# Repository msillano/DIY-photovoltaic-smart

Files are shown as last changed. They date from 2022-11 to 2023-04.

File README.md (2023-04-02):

# DIY-photovoltaic-smart

This study offers an overview of the state of the art and possible alternatives, useful not only for trying their hand at DIY but also for those who have to make choices and evaluate offers in the photovoltaic sector.

Smart photovoltaic projects, with complete technical information, instructions and results:

   - project A: module 300 Wp plug-and-play
   - project B: module 800 / 1000 / 1200 Wp on grid
   - project C: module 800Wp, with limit
   - project D: adding storage to C (1200 Wh)
   - project E: UPS/off-grid hybrid inverter 6200W + storage.
   
Why 'smart'?  All projects they are IOT compatible, therefore they can be controlled remotely and integrated into home automation projects immediately (using the [smartLife](https://play.google.com/store/apps/details?id=com.tuya.smartlife) APP) or via a universal IOT development environment (like [tuyaDAEMON](https://github.com/msillano/tuyaDAEMON)).

---------------

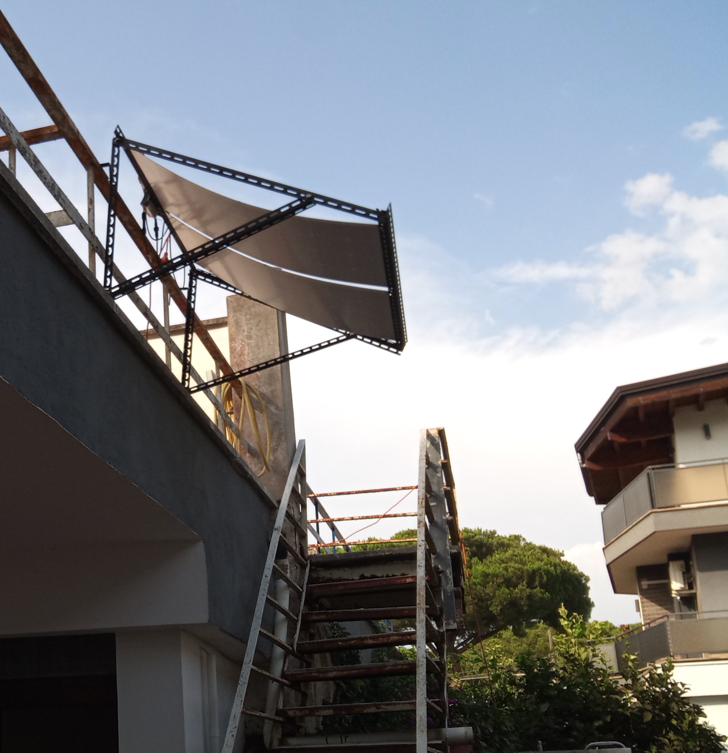
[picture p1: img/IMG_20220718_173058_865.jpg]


Part A: **Preamble about solar, DIY plug-and-play 200/300 Watt**
  - Part A: Wp < 350 W, pdf [english version](fotovoltaico-part-A-v2-en.pdf)
  - Part A: Wp < 350 W, pdf [versione Italiana](fotovoltaico-part-A-v2-it.pdf)
---------------
  
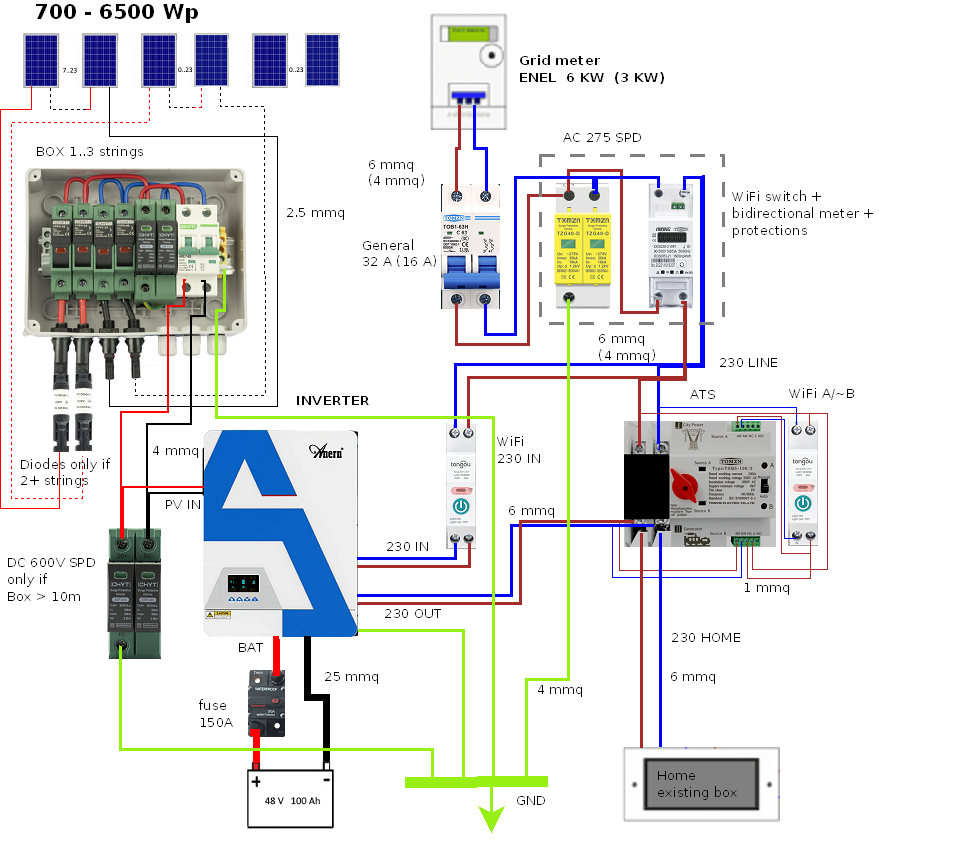
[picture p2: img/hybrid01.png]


Part B: **Usage strategies and DIY photovoltaic > 350 Watt**
  - Part B: Wp > 350 W, pdf [english version](fotovoltaico-part-B-v4-en.pdf) 
  - Part B: Wp > 350 W, pdf [versione Italiana](fotovoltaico-part-B-v4-it.pdf) 

note: _There is a problem with viewing a pdf document within GitHub: the links don't work.
I recommend downloading the pdf file and using a better viewer._

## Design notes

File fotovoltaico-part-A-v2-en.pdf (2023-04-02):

# Photovoltaic today DIY

Part A, ver. 2, 20/02/2023

At the moment, both for the generically green pressures, both for the increases in the electricity bill, both for the problems with fossil fuels, and the government subsidies, photovoltaic systems are on the agenda, in Italy and throughout the world.

As a result, they stick with offers and commercial proposals, which are often smoky and difficult to evaluate.

I try to clarify, sharing both the various analyzes, the projects carried out, and the results obtained, I hope they are useful as a starting point for those who want to try their hand at DIY, and for those who want to evaluate commercial offers.
1. This document is initially a fact-checking, for a correct setting of the problems.
2. Followed by DIY projects of photovoltaic installations less than 350 Wp (plug and play).
3. The next document (Part B) “photovoltaic > 350 Wp” (https://github.com/msillano/DIY-photovoltaic-smart/blob/main/fotovoltaico-part-B-v3-en.pdf) contains more projects.
4. This is a work in progress, with continuous updates. The last version of this document is in the repository https://github.com/msillano/DIY-photovoltaic-smart

The Author is not sponsored or affiliated in any way to any company: the choices are made only on the basis of personal conviction. For the materials, I have tried to favor international suppliers for two reasons:
- Global availability, to be able to carry out these projects anywhere in the world.
- Provide good value for money for comparisons.

Sometimes I refer to the Italian products or the Italian regulatory situation, which I know best, but it is always well highlighted.

Disclaimer
This article is for informational purposes, and is true and accurate to the best of the Author's knowledge, but may contain inadvertent errors or inaccuracies: it is provided "as is", without warranties of any kind, implicit or explicit.

The practical execution of the projects and the sizing calculations of the components and of the electrical connection cables must in any case always be carried out, verified and validated by specialized, competent and qualified technical personnel, in full compliance with all current electrical and safety regulations, which vary according to the country, therefore the Author is not responsible for direct or indirect accidental damages caused by the use of the information provided.

Preamble: simulations

An online simulator can be used to evaluate the potential of photovoltaics.

There are many, the most used (in Europe) is the European Union's PVGIS Photovoltaic Geographical Information System. (https://re.jrc.ec.europa.eu/pvg_tools/en/) I use it often, both in the design phase and in the test phase.

Another good simulator is PVWATTS (https://pvwatts.nrel.gov/pvwatts.php) (NREL-National Renewable Energy Laboratory, USA), analogous to PVGIS.

With PVWATTS you get lower kWh per year than PVGIS (they use different weather data), on the plus side it has an editable satellite map and the ability to analyze the losses in detail.

For an immediate first test, using the optimized values with PVGIS:
1. Choose the location on the map, or enter an address, or the Lat / Lon values
2. For now, select Calculated horizon

Using the 'GRID CONNECTED' tab:
1. Let's set a reference value of 1 (1 kWp) as ‘Installed peak PV power [kWp]’.
2. We select ‘Mounting position’ = ‘Free-standing’ (i.e. with circulating air in the back).
3. We also check the ‘Optimize slope and azimuth’.

Then the button: Visualize results, and then PDF.

The following result is obtained (the location is Rome. Italy):

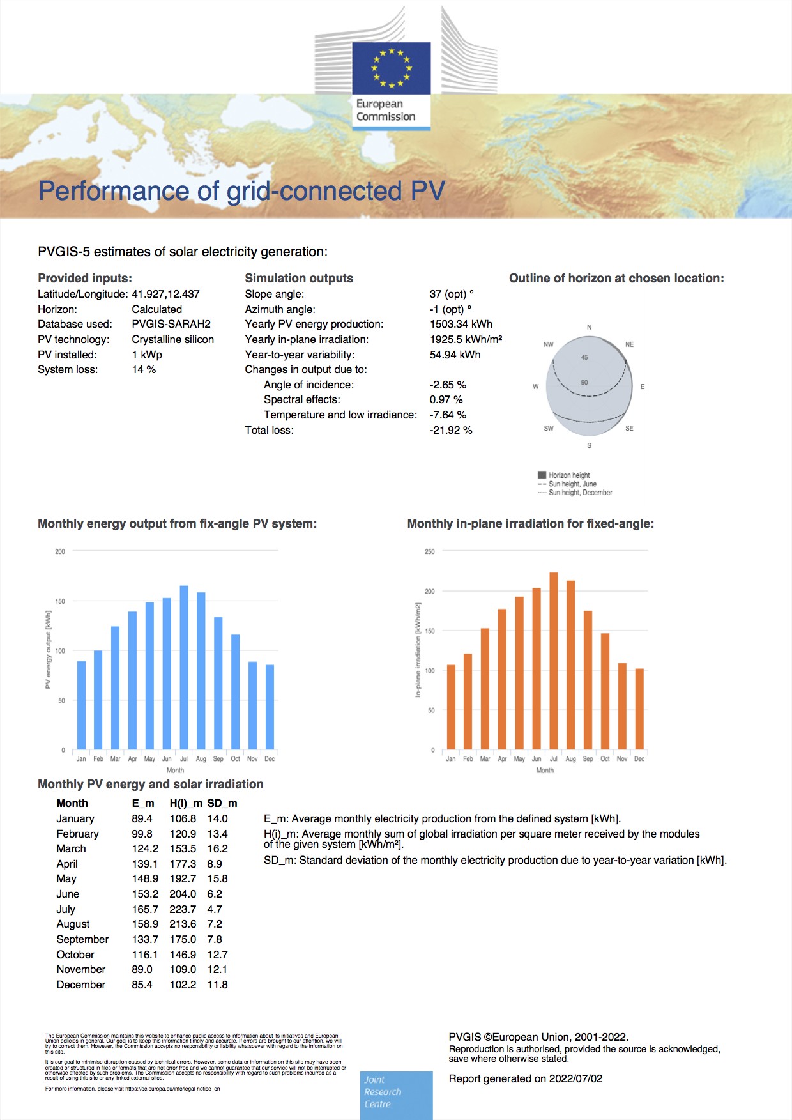
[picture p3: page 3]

Let's analyze some results we get from the simulation:

1. The optimal inclination (slope) of the panel from the horizontal is 37°
2. The theoretical orientation (azimuth) is SOUTH (0°) or noon, but the optimal in this case is 1 ° towards WEST.
3. The calculated horizon, which takes into account natural obstacles, such as mountains and hills, is practically clear: only a small hill at E delays the sunrise (hence the 1 ° correction of the Azimuth).
4. Going with the mouse on the Sun Heigth curves, we find the height of the sun at noon: in June (71°) and in December (24°). From these values derives the optimal proposed value of 37°.
5. In one year the (average, optimal) production of electricity is estimated to be 1503.34 kWh per 1 KWp installed.
6. The month of maximum production is July (165.7 kWh) while the minimum is in December (85.4 kWh).
7. The standard deviation (SD_m) is also indicated for each month, which is a measure of variability. It can be simplified as follows: based on the data of previous years there is a 95% probability of observing an energy production between (E_m – 2*SD_m) and (E_m + 2*SD_m) for the month considered (see 68- 95-99.7 rule). (https://en.wikipedia.org/wiki/68%E2%80%9395%E2%80%9399.7_rule)

The DAILY DATA option, chose a month, provides the average daily irradiation profile.

Clear-sky: does not take into account atmospheric absorption (dust and clouds).

Note: Does not take into
account daylight saving time (DST).

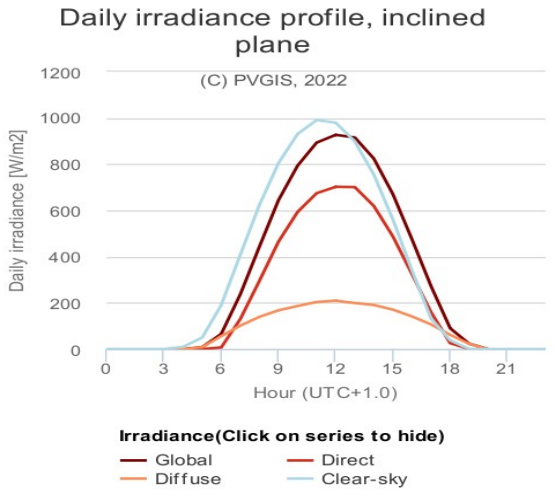
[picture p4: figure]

These are the starting data for the chosen location (in the example, Rome) in optimal conditions.

In practice, what are the factors to be taken into account in the project?
The same as required by the simulation:
- Latitude and longitude of the installation.
- Surface (i. E. KWp) of solar panels, type.

- Mounting system with circulating air (preferable, 'Free-standing') or on a surface ('roof adding') as required in some cases: the efficiency of the panel decreases with the increase in temperature.
- Shadows and geographical and local obstacles, e.g. buildings and trees: are considered by building a custom 'horizon file' (click on 'Upload horizon file' for info) for a given location.
- Slope, or horizontal angle (if fixed)
- Azimuth or orientation (if fixed)
- As an alternative to fixed angles, you can also consider the 'TRACKING PV' option, which is a mechanical tracking system, which transforms the solar panel into a sunflower.

Another fixed point: with standard monocrystalline panels (the most efficient, efficiency >= 20%) the equation applies:

1 square meter = 200 Wp

Use this formula as a litmus test to evaluate offers for solar systems and panels: if an offer promises 1 kWp (1000 Wp), the panels MUST be at least 5 m²
!

Notes: a simulator is simply a sophisticated calculation system based on some assumptions. The results obtained must be verified.

balcony solar panel.

This type of photovoltaic system (called also plug-and-play) is designed for urban users, who live in apartments in the city. The system is very simple and must be thought of as any household appliance: the panels can be installed by the end user in many ways, and they can also be moved. The presence of a plug is essential: these devices do not have to be hard-wired.
These installations aim to reduce the cost of the electricity bill.

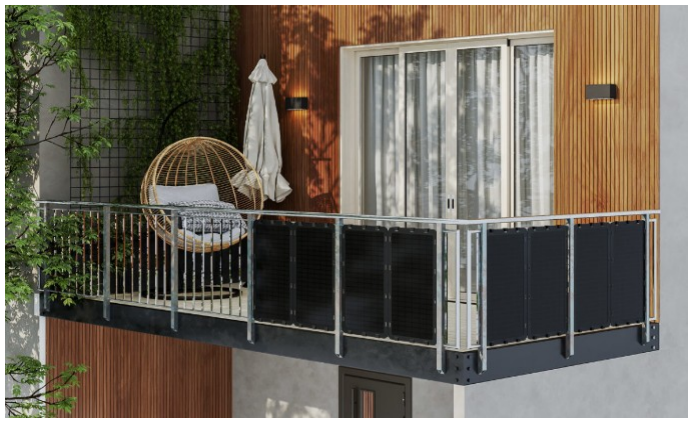
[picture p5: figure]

Example 1: Flexible panels are attached directly vertically to an existing railing.

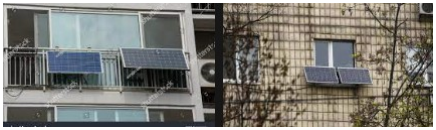
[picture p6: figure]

Example 2: Balcony and window: use of supports to improve the angle of inclination.

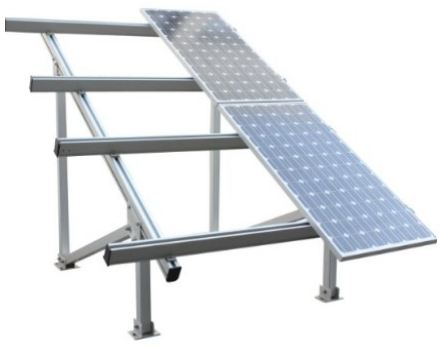
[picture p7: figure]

Example 3: self-supporting for terraces.

Italian commercial example: Enel-x-sun plug-play (https://www.enelxstore.com/it/it/prodotti/campagne/speciale-enel-x-sun-plug-play)

Kit:
1 * rigid solar panel 196 cm * 100 cm, 340 Wp, 1.9 m²
, weight 19 Kg (datasheet) (https://www.enelxstore.com/content/dam/enel-x-store-it/prodotti_catalogo/fotovoltaico/plug-e-play/Specifiche-tecniche-modulo-fotovoltaico-plug-n-play.pdf) 1 * holder, 3 options, weight 7 Kg
(see the manual (https://www.enelxstore.com/content/dam/enel-x-store-it/prodotti_catalogo/fotovoltaico/plug-e-play/Manuale_installazione-plug-n-play-10-06-2020.pdf) in Italian).
1 * inverter, 380 W MPPT TSUN TSOL M350 (https://www.ipersolar.com/it/inverter-grid-connect/1657-microinverter-TSOL300-per-impianti-fino-a-380w.html) 1 * switch + power meter.
Independent video. (https://www.youtube.com/watch?v=mVmnkkBSPkA)
Price: | 649 €
Cost per kWp: | 1900 €

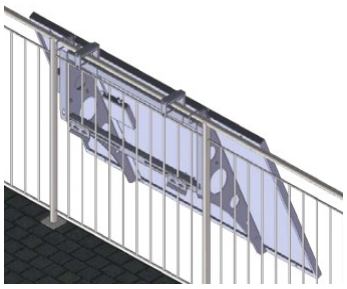
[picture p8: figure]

Italian commercial example: LaCasaDelSole (https://www.lacasadelsolestore.com/index.php?id_product=263&controller=product) Kit:
1 * panel 169 x 99 cm. = 1.6 m², 340 W
1 * inverter TSOL-M350 (certified CEI 0-21) (https://www.lacasadelsolestore.com/index.php?controller=attachment&id_attachment=69)
Price | 650 €
Cost per kWp: | 1’900 €

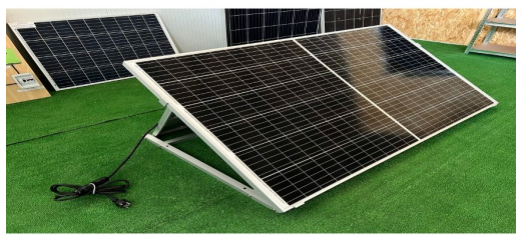
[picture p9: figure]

Commercial example: German startup We Do Solar (https://www.pv-magazine.com/2022/05/17/1-kg-balcony-solar-module-you-can-install-yourself/)

Kit :
8 * flexible solar panels 90 cm * 54 cm (80 Wp), total: 3.8 m²
| , 640 Wp (datasheet) (https://uploads-ssl.webflow.com/61a53640ae89f22ed614b1a3/6263ec536d99d9a6252288c0_Datenblatt.pdf)
1 * Inverter 600 W MPPT
Price: | 1’299 €
Cost per kWp: | 2’170 €

Italian business example: eet-solare. (https://www.eet-solare.it/it/setup/) Kit::
1* Photovoltaic Panel 166 x 100, 370 Wp (MaySun) 1* Inverter Envertec EVT300 MPPT
Mounting accessories
Price | 539 €
Cost per kWp | 1’457 €

Analyses

A series of factors intervene to reduce performance, especially in this type of installation:

### 1. Shadows

Even a small shadow (a leaf) can drastically reduce the performance of a solar panel: this depends on how topologically the individual cells of the panel are connected. If, for example, they are connected in 3 groups, a single cell in the shade leads to a 33% drop in the production of the panel.
The panels connected in series are all affected by the same decline. However, it is possible to use 'power optimizers' which substantially decouple the panels from each other. Similarly, if more panels are connected in parallel, they can be decoupled with protection diodes.

Note: For an evaluation of the shadows of the nearest obstacles (buildings, chimneys, trees, etc.) at various hours and various months, it is possible to use, in addition to the custom definition of the horizon in PVGIS, also a 3D model made with SketchUp-free, (https://www.sketchup.com/it/plans-and-pricing/sketchup-free) as recommended by milliWatt. (https://www.energialternativa.info/public/newforum/Discussione.php?213369)

3. Azimuth
The optimal orientation is the SOUTH, but it is not certain that it is available. Fortunately, the losses are limited: to get an idea of the problem, here is a simple table obtained with PVGIS.
Percentages of annual production (slope = 37°):
SUD 0° | 100%
10° | 99%
20° | 98%
30° | 97%
40° | 95%
50° | 92%
60° | 91%

Note: as the orientation changes, the direct and diffuse irradiation changes during the day, which can be seen in PVGIS, DAILY DATA tab.

### 3. Slope

The optimal slope for our example is 37°. Other inclinations can also be used, for example horizontal (0 °) or vertical (90 °), but with high costs, as shown in the table:
Percentages of annual production (azimuth = 0°):
0° | 84%
30° | 99%
60° | 93%
90° | 66%

Sometimes we are forced to use sub-optimal values: for the exposure of existing roofs, for other architectural constraints, for shadows.

Note: a minimum inclination (eg 5%, equal to 2.8 °) favors the self-cleaning of the panel in case of dry leaves, snow, etc.

Note: as the inclination changes, the powers generated in the various months change, as can be seen in PVGIS. Example:

With an inclination of 75 ° there is a more limited monthly production (min 95.5 kWh, max 113 kWh), but more homogeneous than the optimum.

From the comparison with the monthly results at 37 ° (min 85.4 kWh, max 165 kWh), it can be seen that winter production increases (+ 12%) while production in the summer months is drastically reduced (-31%).

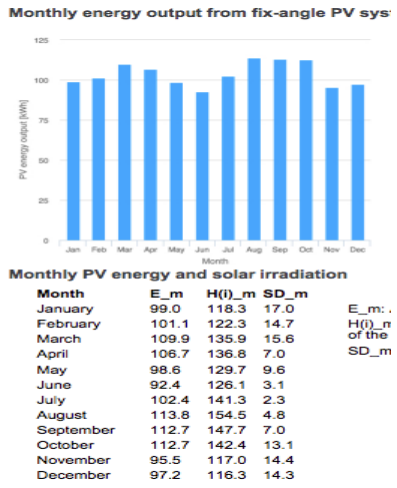
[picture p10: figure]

Optimization can be achieved by manually changing the inclination of the panels twice a year, in spring and autumn, in conjunction with standard maintenance.

### 4. Hourly distribution

With this type of plant, the energy not used in self-consumption is lost, because the excess energy is not remunerated by the electricity companies.
But there is a physiological mismatch between the production and consumption of a family: the hours of maximum production are the central ones of the day, while the hours of maximum consumption are those in the evening.

The following figure schematically represents the typical consumption of a private user: there is a peak in the morning and a second peak in the afternoon-evening.
Compared with the energy produced by the photovoltaic system, the yellow area is the excess energy, the blue one is the energy supplied by the grid, in green we have self-consumption.

Note: the figure refers to a plant of at least 1.5 kWp, but even after reducing the yellow peak, the substance does not change.

In reality, the consumption curve is very variable: it obviously depends on the appliances installed, for example, water heaters and air conditioning are very energy-intensive. Ditto for electric ovens and induction hobs. Furthermore, the curve also depends on the habits of the users.

In Italy building permits are not required as long as the panels are mounted adherently on pitched roofs or walls. See GSE guide. (https://www.vegaengineering.com/mlist/uploaded/GSE%20-%20guida%20integrazione%20architettonica%20del%20fotovoltaico.pdf)

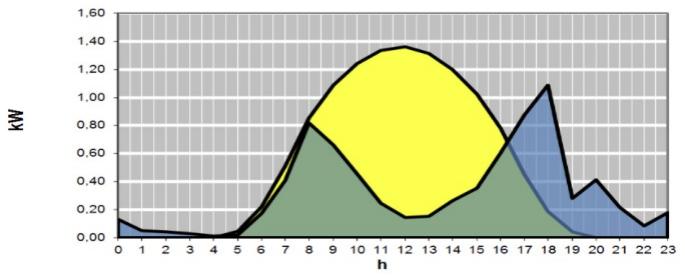
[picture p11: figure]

In practice, action must be taken on two fronts:
- Obtain experimental graphs for hourly consumption.
- Try to shift consumption towards daytime, for example by timing the switching on of the storage water heater, or by changing habits and using the washing machine at 2 pm, etc.

The goal, all in all simple to achieve for small powers, is to have consumption, during the day, higher than the power generated by the photovoltaic system. In this way, all the energy produced for self-consumption is used, without waste.

Notes: it is evident that, with systems with this strategy, it is never possible to cancel the electricity bill: there will always be consumptions out of hours.

But you can achieve the goal of producing and using solar energy with reduced waste, maximizing the reduction of billed electricity consumption,

Annual consumption per family

Nazione | 1 person 2 people 3 people
Italy (ENEL) | 1434 | 2081 | 2581
Italy (ISAE) | 2168 | 2694 | 3134
Austria | 2226 | 2910 | 4187
Malta | 1400 | 1850 | 2175
Spain | 1415 | 1924 | 2299
Netherlands | 2220 | 3095 | 3875
Belgium | 1575 | 2200 | 2705 (font KiloWattene) (http://kilowattene.enea.it/KiloWattene-consumi-famiglie.html)

For each kWp installed, the maximum theoretical photovoltaic production is 1500 kWh/year (Rome, see initial simulation).
For comparison:
- The 350 Wp Enel plant will produce 525 kWh/year (maximum) in Rome
- The 640 Wp We Do Solar plant will produce 960 kWh/year (maximum) in Rome These 'average' values must always be verified on a case-by-case basis, for example using the electricity bills of previous years.

# DIY Plug and Play solar panel

A1 project (200 W):
2 * flexible solar panel 105 cm * 53 cm,
RG-MN-100 | 176.34 €
1 * multipurpose holder,
made of iron profile. | 12.00 €
1 * switch + meter 20A EU Tuya | 16.36 €
1 * inverter , 300 W GMI -300 | 53.06 €
In Italy: inverter TSOL M350 | 228.54 €
Cost: | 258 € (Italy: 433 €)
Cost per kWp: 1280 € (Italy 2167 €/KWp)

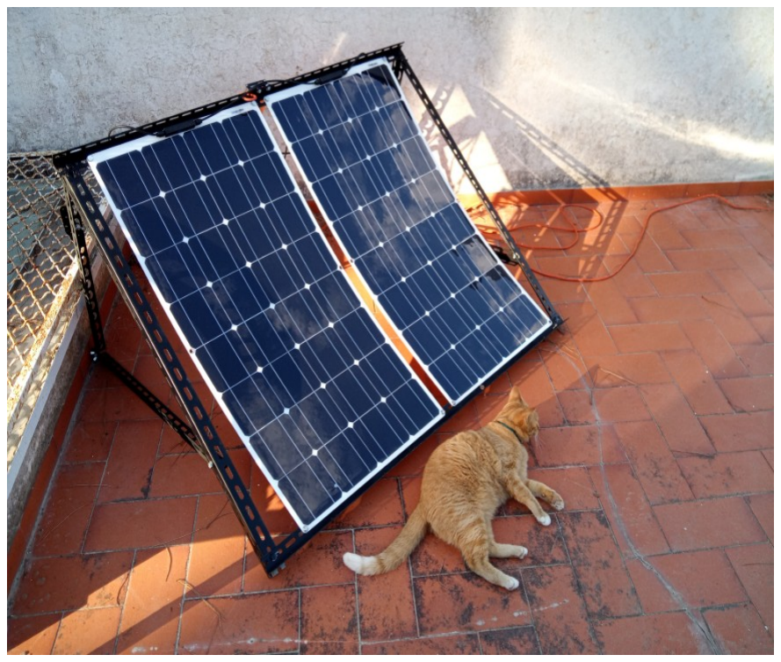
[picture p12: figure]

This project was developed and implemented mainly for experimentation and verification of simulations. Low cost and in a concrete case.

Note: The prices indicate the amount I paid, including shipping (June-July 2022). Prices can obviously vary: carefully select the supplier
Project criteria
The final goal is to reduce the amount of the electricity bill, therefore the objectives of the installation are:
- Cost per kWp as low as possible
- Containment of the inevitable losses due to non-optimal orientation and inclination, presence of shadows, etc.
- I use, where possible, Tuya-compatible (https://pages.tuya.com/expo/contact_form) control and measurement devices, to have automation and remote control at no cost. For the most demanding users, it is available TuyaDeamon, (https://github.com/msillano/tuyaDAEMON) a development environment open-source for IoT.
I do not want to use proprietary clouds, and therefore not even the proprietary remote control WiFi APPs, apart from Tuya (https://pages.tuya.com/expo/contact_form) devices and the smartLife APP. (https://ismartlife.me/) Already deciding to use Tuya and its cloud was a difficult decision, justified by the high-security systems, the high performances, and the peculiar commercial position of Tuya as a provider of services to third parties - see 'why TuyaDAEMON' (https://github.com/msillano/tuyaDAEMON/wiki/why-tuyaDAEMON-%3F) (in Italian: 'perchè TuyaDEAMON'). (https://github.com/msillano/tuyaDAEMON/blob/main/perch%C3%A9-tuyaDEAMON.pdf)

Modularity

I believe it is valid to design and use identical autonomous modules, to be multiplied if more power is required.
The advantages are as follows:
- Greater flexibility: when, for reasons of space, you want to use two different orientations (see the previous photo of the balcony), there is greater efficiency if each group of panels has its own MPPT controller.
- Greater resilience a failure causes less damage and is cheaper to repair. With little expense, you can stock spare parts: a panel and an inverter.
- Ease of later expansion for example, if you add new appliances to your home.

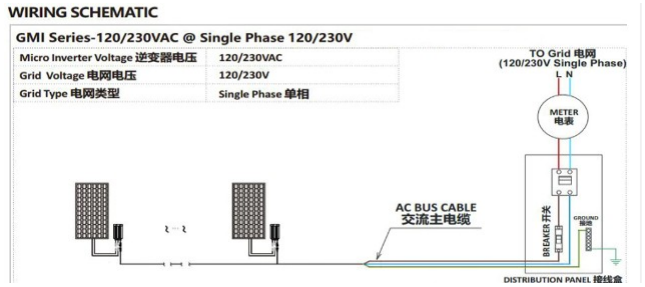
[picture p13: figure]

Photovoltaic panels
Flexible panels have several advantages over those with frame and glass, especially in the DIY case:
- Reduced weight, the problems of transport, installation, supports, etc. are simplified.
- Small size (½ m²
.): Greater positioning possibilities
- Great reusability, multiple fixing and use options (on vehicles, boats etc.)
- Better resistance to hail damage than rigid panels.
- High performance and low cost.
- In these months the rigid panels have very long delivery times. The flexible panels are ready.

The selected RG-MN-100 (https://www.alibaba.com/product-detail/save-electricity-durable-16V-100W-mono_62206562525.html) model has these characteristics:
power 100 Wp, dimensions 1050x530x2.5mm, weight 1.9 kg, open circuit voltage 19.2 V, DC current 6.87 A, efficiency 20.5%, life 25 years
It has 6 stainless steel eyelets on the perimeter for fixing. The length of the cables allows the connection of two panels in series and an inverter without the need for extensions or other accessories.
Fast delivery to Europe via Aliexpress from a warehouse in Poland. (https://it.aliexpress.com/item/4001199723442.html)

There is also the possibility, if you are lucky, to find second-hand solar panels at very attractive prices (see example). (https://www.google.com/url?rct=j&q=&esrc=s&cd=&cad=rja&uact=8)
Inverter
Many Italian plug-and-play kits use Zucchetti blue as inverter, or the TSUN TSOL M350, with CEI 0-21 (https://www.enelxstore.com/content/dam/enel-x-store-it/prodotti_catalogo/fotovoltaico/Certificazione%20microinverter%20-%20Tsun.pdf) certificate.
Microinverter TSUN TSOL 300W (https://www.amazon.it/gp/product/B0BTYW6144/ref=ox_sc_act_title_1) | € 228,54

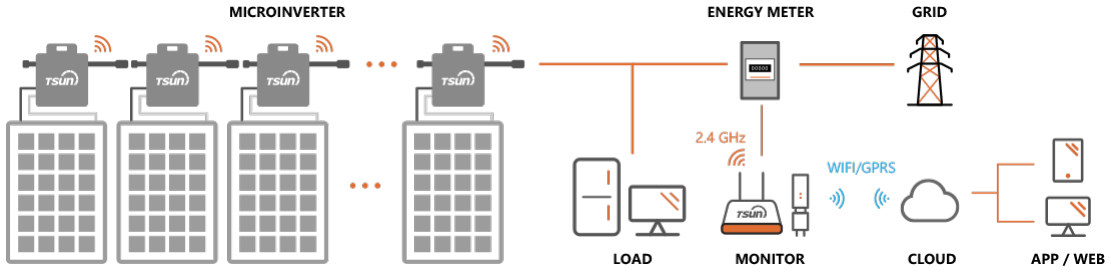
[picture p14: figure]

Without the CEI constraint (not in Italy) I would choose for the plug-and-play photovoltaic project, the very simple and low-cost inverter, GMI300 (http://www.allofsolar.com/index.php/content-64) slightly oversized (300 W) to reduce overheating problems (see datasheet (http://www.allofsolar.com/download/datasheet/GMI260-350_Series_Datasheet_EN_V1.9_2021_04_02.pdf) and CE certificate) (https://ae01.alicdn.com/kf/S582a2a7fb2fd4b9eb167c4d806f8ef88i.jpg) even if this involves a decrease in yield.
This inverter has two automatic shut-down levels in case of high temperatures: 50% and OFF.

If you mount the inverter close to the panels, (preferable solution) it is necessary to ensure that it is at least under the panels, in the shade and sheltered from the rain, connected to a metal structure to improve dissipation, while the solution of mounting the inverter to the internal, on a panel, can be valid in particular cases, but has the following defects:
- Reduction of modularity and portability
- Increased costs and losses for long large diameter DC cables (current 7 A).

The problem of overheating must be felt if the manufacturer also offers two spare parts kits, see instructions on the video (https://www.aliexpress.com/item/1005002995427499.html) (this was also a positive factor of choice).

Users presented various dubious solution hypotheses, such as holes, fans, etc.
The most valid, in my opinion, and which does not compromise the P55 specification, is to mount the hottest side (the bare aluminum one) in contact with the supporting metal structure, which will act as a heat sink.
It is also possible to add an external finned heatsink (in the photo, a user's oversized solution). (https://www.aliexpress.com/item/1005001947974383.html)
I tested the inverter in July 2022 (35 ° C) without a heatsink and without problems, measuring an external temperature of 55 ° C. The panels reach 61 ° C.

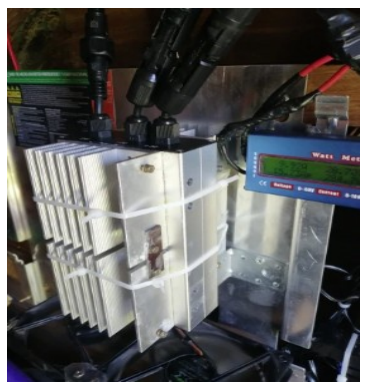
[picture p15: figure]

However, here is an example of an additional heatsink: 100x60x10, 4.09 €, (https://www.aliexpress.com/item/1005004124759503.html) to be connected not with nylon ties, but with parker screws and a lot of heat-conducting paste.

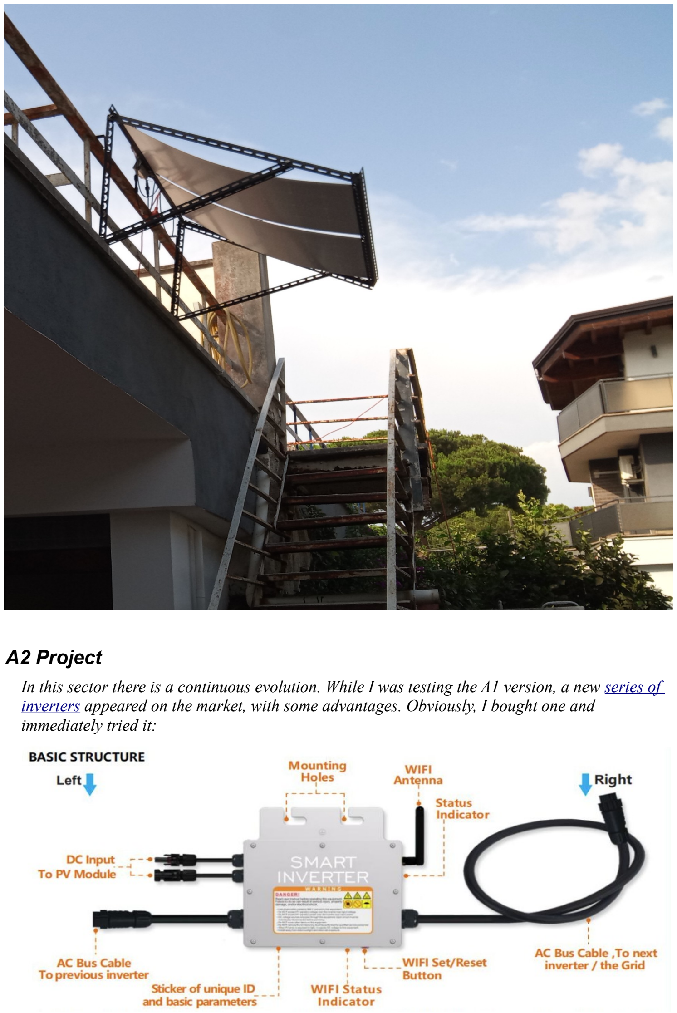
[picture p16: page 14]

A2 Project
In this sector there is a continuous evolution. While I was testing the A1 version, a new series of inverters (https://it.aliexpress.com/item/1005004388047473.html) appeared on the market, with some advantages. Obviously, I bought one and immediately tried it:

An advantage of the Y&H SG-300W is the better connectivity (at 220 and DC) which offers simplicity and savings of accessories (cables, diodes, joints). Another is the Tuya/SmartHome compatibility, which allows for easy control.

A2 project (300 W):
3 * flexible solar panel 105 cm * 53 cm,
RG-MN-100 | 264.51 €
1 * multipurpose holder, made of iron profile. | 15.00 €
1 * inverter , 300 W SG300MS (https://it.aliexpress.com/item/1005004388047473.html) | 104.65 €
Cost: | 384 €
Cost per kWp: | 1280 €

Similar to the A1 version, it uses a different inverter and does not require the 'switch + meter 20A EU Tuya', as the WiFi function is present in the SG300 inverter.

DIY Plug-and-Play solar panel: realization

Step 1: analisi consumi

The first step I took was the replacement of the lifesaver in the electrical panel of the house with a compatible Tuya life saver + wattmeter, for a better analysis of domestic consumption (optional).

2P 63A TUYA APP WiFi Smart Energy Meter OPWT-63 (https://www.aliexpress.com/item/1005002361164427.html, € 33) See also Tuya info. (https://github.com/msillano/tuyaDAEMON/blob/main/devices/BreakerDIN/device_BreakerDIN.pdf)
In addition to the measurement function (V, I, W, kWh) visible on the display, this switch has adjustable protections for:
- Leakage (10-100 mA) (same as lifesaving)
- Overcurrent (1-63 A) (same as magnetic)
- Overvoltage (250-300 V) 0.5 s delay
- Undervoltage (150-190 V) delay 0.5 s

Among the many devices available, I chose this model because it has the same dimensions as the existing life-saver breaker, so the replacement into the home switchboard is very simple.

This meter provides (with the SmartLife App) a daily graph, which is exactly what you need to evaluate electricity consumptioni.

We see how the consumption of a day (July 8) is mainly evening-night, while the basic value (about 100 W) is the sum of the standby of TV, WIFI, PC, irrigation etc.

Note that hourly integral values are indicated in the graph: peak values can be greater (up to 3.3 KW).

The data provided by the OPWT-63 Meter can also be used in rt with

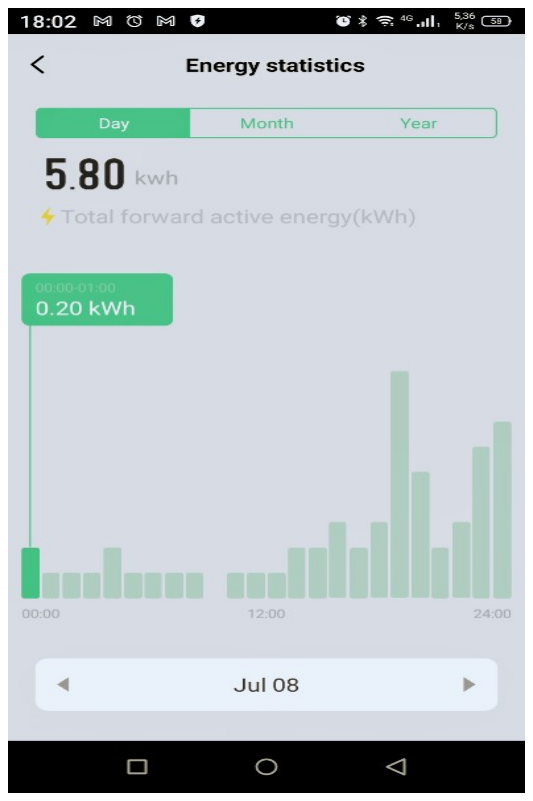
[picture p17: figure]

tuyaDAEMON: here is the consumption of 24 hours

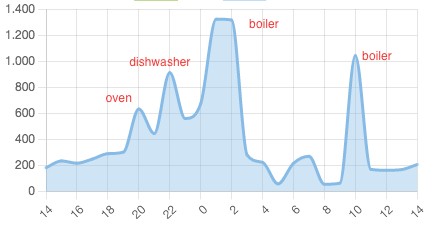
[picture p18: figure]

Notice:
- minimum < 100 W
- evening 300W
- peaks due to household
appliances.

The biggest peak is
caused by the storage
water heater (boiler
1300W)

Note: in Italy, the e-distribution APP offers similar 'load curves', but with some delay.

Step 2: supports

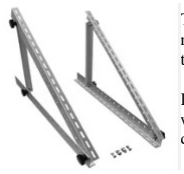
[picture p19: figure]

Taking commercial models (https://it.aliexpress.com/item/32974424084.html) as an example, as in the figure, the mobile support was made with perforated L-shaped iron profiles (the type for shelves) mainly because they were available!

It can be made in wood, or, better using aluminum - this presents welding problems for me - always bearing in mind an assumed duration of 20 years.

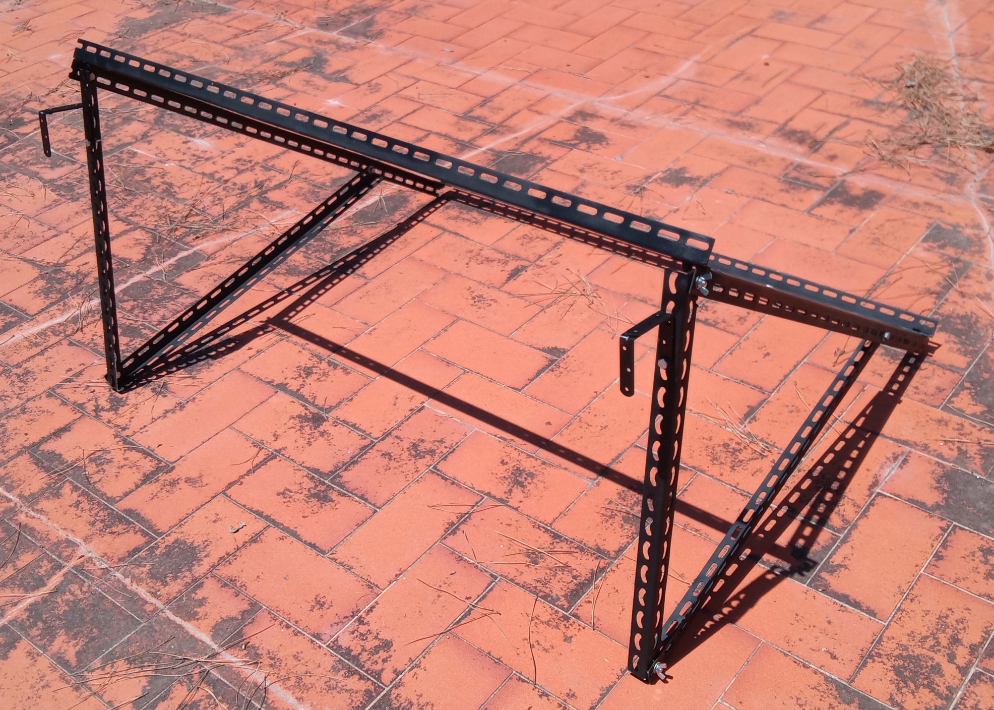
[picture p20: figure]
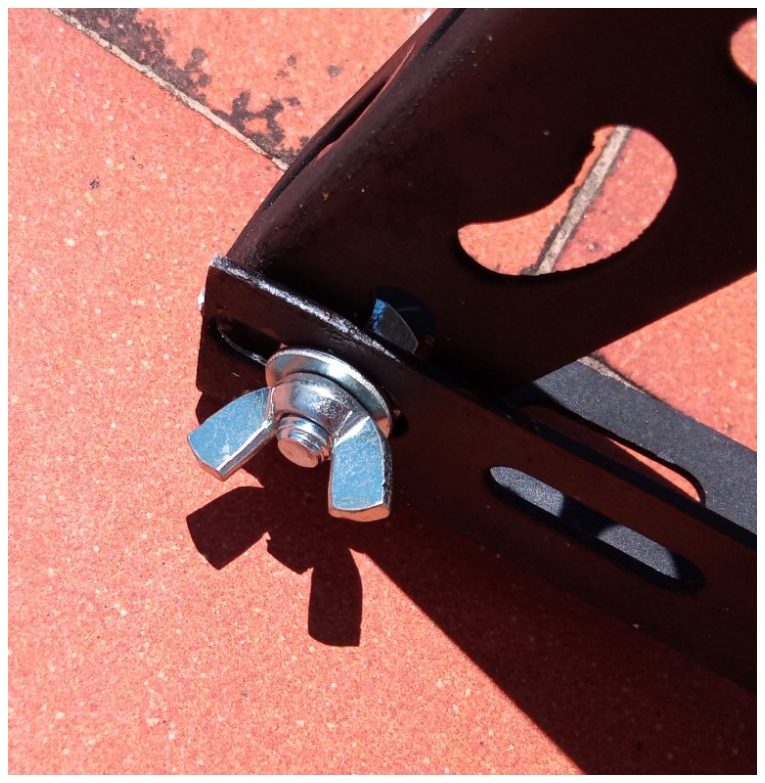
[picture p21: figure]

In reality, there are only two welding points at the vertices of the main rectangle, to provide rigidity: the assembly is all done with 8 mm bolts, with nuts or butterflies.

The railing brackets are made by joining two 'L' with rivets and creating an 8mm hole.
The only critical measurement is the vertical side of the frame, equal to the length of the panels (105 cm).

This support is universal, it can be used on railings, windows, walls... The inclination is easily adjustable to carry out all tests.

Total weight 14 kg:
support | 9,7 kg
panels | 3.8 kg
inverter | 0,5 kg

notes on fixing: DIY does not mean unsafe: provide stability in case of strong winds (at 40 m / s the pressure is 190 kg / m2), (https://www.highpeaktent.com/it/page/beaufort-scale-wind-speed-and-wind-pressure.html) on railings also use a lower fixing, and use a second safety system (e.g. with nylon ropes) anchored to the frame, to avoid accidental falls (see Enel instructions). (https://www.highpeaktent.com/it/page/beaufort-scale-wind-speed-and-wind-pressure.html)

On a flat surface, weights (https://www.mediterraneabeton.it/zavorre-in-calcestruzzo/) (TSUN recommends at least 20 kg.) (https://www.mediterraneabeton.it/zavorre-in-calcestruzzo/) and safety cables should be used so as not to puncture the flooring.
Here is another example, (https://www.sunballast.it/) but we can use flower pots or cheap umbrella bases filled with water or sand (€ 9).
Step 3: fixing panels

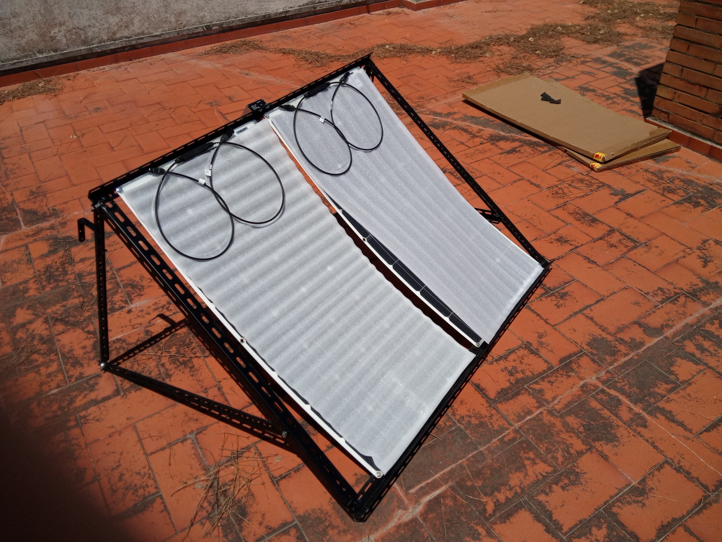
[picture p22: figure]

Flexible solar panels can be installed using various systems:
- On an existing surface (walls, vehicles and campers, boats, etc ...) you can use simple double-sided tape!
- Or even self-adhesive velcro, if you want to move them quickly.
- Even using zips 'sewn' to the edges of the panels (for boating).
- They can also be fixed with ropes passed through eyelets (e.g. on balcony railings).

To fix the panels to the frame I simply used 4 6 mm stainless steel bolts with self-locking nuts. If you want to increase the rigidity, you can add a sheet of alveolar polycarbonate under the panels, increasing however the costs and worsening the ventilation.

Step 4: connection
To work, this inverter must be connected to the 220 grid: it cannot, therefore, be used as an uninterruptible power supply (UPS).

It is safe to use any socket in the existing system because if the socket is not live the inverter stops working, eliminating any risk.

The rules vary from country to country: comply with current regulations.

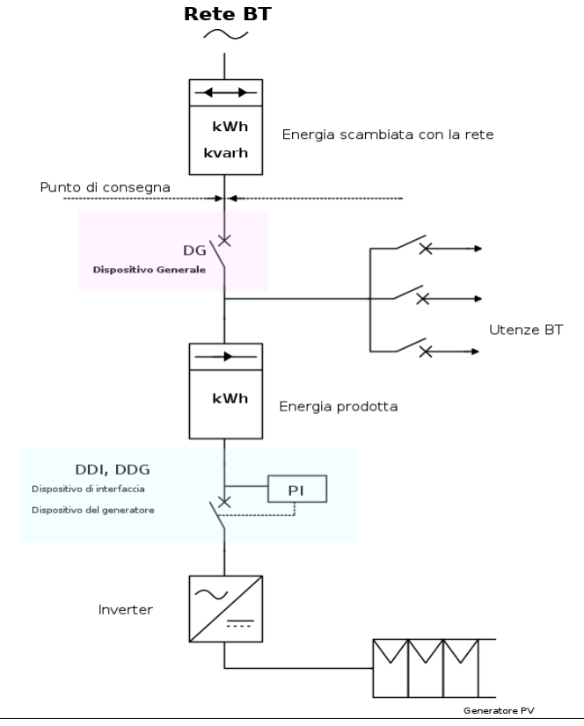
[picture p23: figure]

Many commercial kits simply use a smart switch (https://www.aliexpress.com/item/1005003640472196.html) (€ 16.36), to ensure mobility, which performs multiple functions:

As DG (on the home panel) I used the 'WiFi Smart Energy Meter' (see above), which, in addition to acting as a switch, integrates some protection and WiFi functions.

As DDI + DDG you can use a circuit breaker with protection, or a second Smart Energy Meter (see above), with breaker and differential and magnetothermic protection functions, in a small distribution box (e.g. enel-x-sun).

In Italy, according to resolution ARERA 315/2020/R/EE, (https://www.arera.it/allegati/docs/20/315-20.pdf) the generator must be connected to a 'dedicated socket', connected between the DG and the other users (see diagram, source https://electroyou.it/admin/wiki/schemes-photovoltaic-in-bt) or even this. (https://www.eet.energy/wp-content/shared/uploads/2022/03/Schema_Italien.pdf)
A DDI device must allow the protection of the users and the disconnection of the generator.

- The button on the body acts as a manual switch for the solar panel
- With the SmartLife application it is possible to remotely control the ON / OFF function
- With SmartLife it is possible to read V, I and W snapshots remotely.
- With Smartlife you also have the daily kWh with both monthly and annual totals and graphs.

See also Tuya info. (https://github.com/msillano/tuyaDAEMON/blob/main/devices/Smart_socket/device_Smart_socket.pdf)

The protection for extra voltages is entrusted to the WiFi Smart Energy Meter device upstream. In the A2 project, the smart switch is not necessary and the inverter can be directly connected to a home socket.

Automation: tuyaDAEMON
With this project, both the grid information (power, cumulative consumption) and the information relating to the solar generator (rt power, kWh generated) are available remotely via SmartLife. If desired, the solar generator can also be set to OFF.

Unfortunately, the automatisms available with smartLife are not advanced enough to be useful in the management of this photovoltaic panel, apart from the timed start and shutdown.
Also a simple ON / OFF strategy cannot be implemented in smartLife: “insert the photovoltaic energy only when consumption exceeds the power produced, and disconnect when the energy consumed is less than the energy produced, so as not to send energy to the grid”.

Instead, this is possible with tuyaDEAMON, (https://github.com/msillano/tuyaDAEMON) used with the function of a super-controller, which integrates the entire Tuya ecosystem - sensors, switches, photovoltaic - with a database, custom extensions, and high-level logic.

Step 5: performance
The default yield that the PGIS simulator uses is equal to 16.4% (from the ratio between annual kWh produced and annual irradiation).
The real yield is variable, as shown in the following table (a few hours for shade on the panels are excluded), where the 'irradiation' column comes from PGIS, 'daily data' tab. The 'power produced' data is read every hour by the Smart Switch.
Measurements (17 Sept.) clear day, inclination 37°, south orientation (0°)
time | Irradiation (Wh/m² ) | Power (W) | Yield (%)
9:00 | 570 | 78 | 13,7
10:00 | 730 | 99 | 13,6
11:00 | 813 | 120 | 14,7
12:00 | 837 | 124 | 14,8
13:00 | 787 | 123 | 15,6
14:00 | 686 | 100 | 14,6
15:00 | 516 | 80 | 15,5
Tot. | 4939 | 724 | 14,7

The average yield is about 15%, lower than the expected value (16.4%) estimated by PVGIS.

1. In inverters it is common to decrease the efficiency as the power decreases
(inverter specifications: Pmax: 300W, CEC efficiency at 220V: 91.5%).
2. Furthermore, the global irradiation data estimated by the PVGIS, which takes into account the clouds, may differ from the real values. I have noticed very different values in at least one case.
3. Further investigation should allow us to pinpoint the exact cause of the discrepancy, but let's continue with the actual measured values.

In the PVGIS simulator, it is possible to empirically increase the losses (default 14%) to obtain a similar yield.

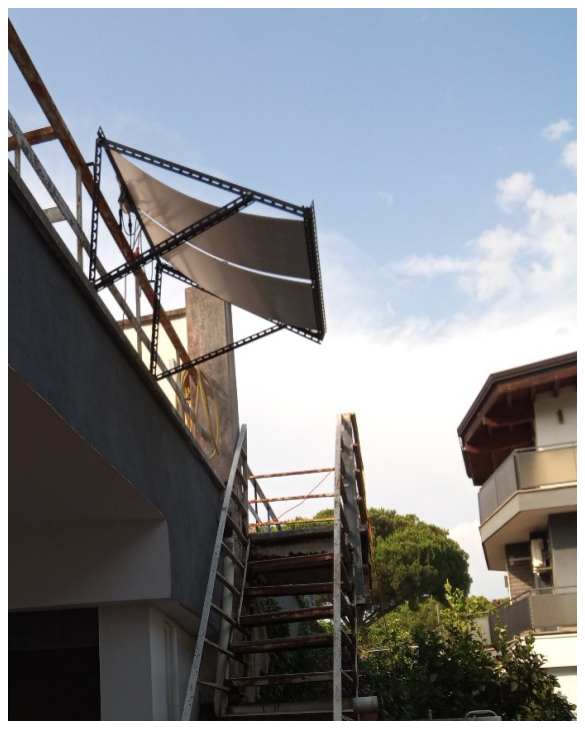
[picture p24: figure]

Graph of the total power, power from photovoltaics and power from the grid (10 October 2022, from tuyaDAEMON):

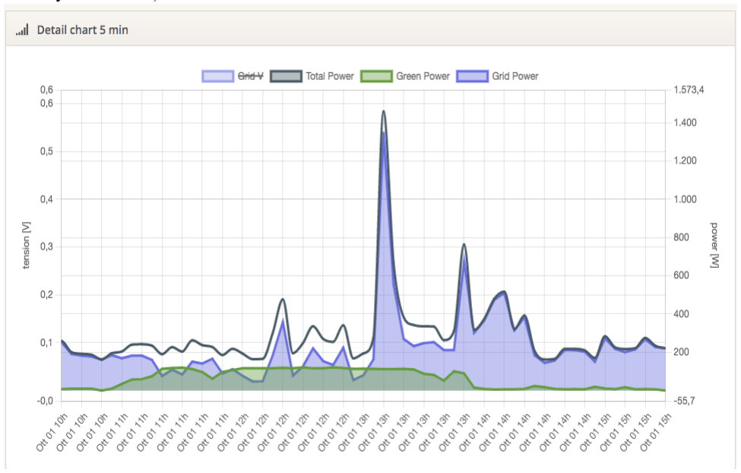
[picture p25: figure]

As you can see, the hours are reduced (from 11:00 to 15:00) both for clouds and for exposure.

Economic return

Starting data (Italy, third quarter 2022):
Cost of energy materials: | 33.08 c€/kWh.
Energy cost in the bill (Source ARERA): (https://www.arera.it/it/dati//aggtrim.htm#ele) | 41.51 c€/kWh.
system cost: | 258 €
annual cost (cleaning, spare parts, etc.): | 20 €
annual production: | 220 kWh (yield 15%)

Hypothesis 1: optimal position, total self-consumption: 100% (220 kWh/year) Amortization: 3 years, 8 months
Investment Return: 17.21%

Hypothesis 2: not optimal position, partial self-consumption: 60% (132 kWh/year) Amortization: 7 years, 7 months
Investment Return: 3.22%

font: https://www.sunearthtools.com/it/solar/payback-photovoltaic.php

note: Tracking systems
You can have systems with a single axis (normally parallel to the earth's axis) to point the sun from sunrise to sunset, or with two axes to also follow the height of the sun.

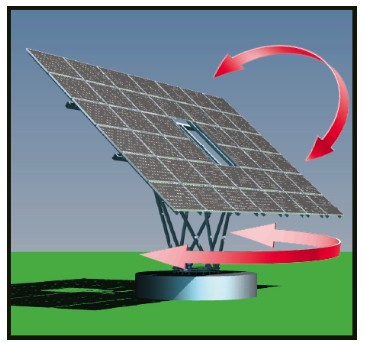
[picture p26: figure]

Benefits:
- PVGIS shows an increase in the energy produced by 31% (2088 vs 1586 kWh / year).

Disadvantages:
- Solar panels are quite heavy objects and the mechanics needed to move them safely are neither simple nor cheap.
- Electronic control systems, maintenance, consumption etc. must also be considered.
- With movement, each panel requires more space and generates shadows. (https://www.rinnovabili.it/energia/fotovoltaico/inseguitore-solare-aumentare-resa-moduli-fotovoltaici/)

Examples:

Single Axis Solar Auto Tracking Controller (https://it.aliexpress.com/item/1005004983932807.html) (NS)
81.40 €

Pan-Tilt with double axis (https://it.aliexpress.com/item/1005004724245499.html) DC, 25 Kg
(mechanics and engines only) | 85.60 €

Conclusion:
Using normal monocrystalline panels, only by finding a simple and inexpensive system, which costs less than 20% of the installation, can the pursuit be considered. Not (at least for now) of DIY interest.
However, it is possible to evaluate the manual modification, twice a year, of the 'slope' of the panels.

Conclusions on plug-and-play DIY

The plug-and-play DIY solar panel has production shown between 9:00 and 15:00 (solar) in July, with a total between 0.6 and 0.7 kW/day.

There is therefore a self-consumption of 100% if between 9:00 and 15:00 the electricity consumed is equal to or greater than the production (70-120 W).

In this case, all the annual production (estimated 220 kWh) is used, with an annual saving (Italy, current prices) of 90.2 €. with a very short amortization period (about 4 years).
- The panels degrade over time: the life of the solar panels is estimated 20-25 years.
- Ordinary maintenance required: every 6 months cleaning of the surface of the panels.
The most favorable situation occurs when there is already constant electricity consumption during the day: public places, greenhouses or hydroponic crops, electronic equipment, fans, etc. Otherwise, it is necessary to shift the usual consumption to the hours of sunshine.

The importance of a tailor-made 'energy strategy', possibly implemented with the help of automatic IoT control systems, such as TuyaDAEMON, is evident.
Permissions and obligations (plug-and-play)
Warning: in standard conditions, the electricity meter counts the surplus of energy fed into the network by the user as consumption.
In general, a communication to the distribution company can allow the (modern electronic) meter to be enabled for bidirectional operation, but, usually, the energy transferred to the network is not remunerated: for the user it is lost.

The rules (and incentives) vary by country and by the supplier company.

In Italy a plug and play photovoltaic system (Wp <= 350 W) (https://www.arera.it/it/com_stampa/20/200807.htm) is facilitated:
1. can be installed by the end user
2. must be made in compliance with the CEI 0-21 Standards
3. does not require permits, except for a possible 'communication' (https://www.enelxstore.com/content/dam/enel-x-store-it/prodotti_catalogo/fotovoltaico/plug-e-play/Comunicazione-Preventiva-Fotovoltaico.pdf) to the condominium, or an authorization in the case of historic center subject to 'landscape constraints' (information to the municipality, see also sentence of the Lombardy Tar No. 496/2018 (https://www.donnegeometra.it/portfolio/tar-lombardia-sez-iii-sent-n-496-del-18-gennaio-2018) on the visible/invisible problem).
4. must be communicated to the local network operator by completing and sending the "Comunicazione Unica per impianti di produzione di potenza inferiore a 800 W" form available on the ARERA website, at the following link: https://www.arera.it/allegati/docs/20/315-20.pdf or filling a form online on the e-distribuzione (https://www.e-distribuzione.it/) site (“iter semplificato”) (https://www.e-distribuzione.it/content/dam/e-distribuzione/documenti/produttori/modelli_informative/GUIDA_AREA_PRODUTTORI_2020.pdf) at no cost.
As a result, the meter is enabled (bidirectional) so that the user does not find the excess energy produced in the bill, but the energy transferred to the grid is not remunerated.

Addendum

AUGUST 25, 2022 (https://www.pv-magazine.com/2022/08/25/german-state-supports-balcony-solar-power-generation-via-rebate-program/) The government of Mecklenburg-Vorpommern has allocated €10 million ($9.93 million) to support the deployment of balcony solar modules with a power output of up to 600 W.

JANUARY 28, 2023 (https://www.pv-magazine.com/2023/01/28/weekend-read-small-change-big-effect/) Starting this year, ground-mounted solar modules in Germany can be replaced before the end of their service life.“Used modules can provide relief on the sold-out market and can be used for balcony photovoltaic systems, for example,” says SPD’s Gremmels.

Note: the "simplified" online e-distribution process is only apparently simple (see guida). (https://www.eet-solare.it/it/blog/comunicazione-unica-plugplay/) The DIY user can make silly mistakes the first time just because some useful information is not easy to find on the site. (https://www.e-distribuzione.it/a-chi-ci-rivolgiamo/produttori/portale-produttori0.html) For instance:
- The registered letter of adhesion (Form + photocopy of identity document, paper copy) must be sent to “e-Distribuzione, CP240, 00071 Pomezia, RM” and NOT to other addresses on the site. Keep the receipt!
- The same form must be submitted a second time electronically, together with another PDF copy of the doc of identity and with a copy of the receipt of the registered letter (! sob). The form, in PDF format, must be complete (7 pages), even if signed only on the last page (!). As there is a 3Mb limit, the 7 pages must be sent as 7 separate files (!).
- Access to the various forms is compulsorily sequential, even if the page is counter-intuitively structured with tabs.
- If you need to perform a subsequent update action - called INTEGRA (integration)- you must always restart from the first step (even if the INTEGRA tab is present: you must not use it immediately): a lot of nonsense.
When I communicated my plug-and-play A1 system to e-distribution (indicating the brand of the inverter Taozhong New Energy and model GMI300W), the request of August 25th was processed on October 13th, because I make all previous 'blocking' mistakes.

Note: In Italy there is an additional temporary incentive for the purchase of solar panels, inverters and batteries: 50% refund on future taxes (eco-bonus). Some large companies offer a discount on the invoice for the amount of the incentive (invoice discount ended 17/2/2023).

Also in Italy, for systems with power greater than 350 Wp, but less than 800 Wp, the following documents are required (see example), (https://www.eet-solare.it/it/blog/comunicazione-unica-plugplay/) which can represent a difficulty in the DIY case:
- Single-line wiring diagram of the system
- Declaration of conformity of the production plant to the rule of the art in accordance with current legislation
- Declaration of conformity of any static conversion and interface devices installed
- Operating regulations signed by the manufacture

JANUARY 30, 2023 (https://www.pv-magazine.com/2023/01/30/swedish-authorities-issue-warning-about-solar-panels-on-balconies/) The Swedish Electrical Safety Authority (Elsäkerhetsverket) has issued a warning about the risks posed by plug-in solar modules, which are often used on balconies. It said electrocution and fire are the main risks associated with faulty plug-in panels.

FEBRUARY 1, 2023 (https://www.pv-magazine.com/2023/02/01/swiss-manufacturer-unveils-mini-batteries-for-balcony-solar-panels/) Soleis AG's new Minitower1 battery system can store solar power from balcony PV modules.

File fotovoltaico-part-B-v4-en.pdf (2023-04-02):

# DIY Photovoltaic > 350 Wp

Part B, Ver.4, 20/03/2022

As seen in Part A, (https://github.com/msillano/DIY-photovoltaic-smart/blob/main/fotovoltaico-part-A-v2-en.pdf) even in the case of 100% self-consumption, a 350 Wp plug-and-play system produces relatively low savings (11.4% - 8.4%) compared to the annual consumption of a family of two (2000 -2700 kWh/year). For higher percentages, it is necessary to review the projects.

By increasing the power of the system new problems arise for the installation of the panels (now fixed) which require at least 5 m²
for each kWp, with the same exposure and without shadows. Even the connection to the grid is complicated compared to the plug-and-play case, which is mobile by definition. With high powers, the strategies that can be used (https://www.iorisparmioenergia.com/it/blog/guida-agli-impianti-fotovoltaici/impianto-fotovoltaico-ad-isola-o-connesso-a-rete) for the management of the energy produced also change:
1 Systems connected to the grid ('grid tie' or 'on grid'). Subject to constraints that vary by country and electricity distribution company. They manage any load: the necessary energy can always be supplied by the grid. Important: They don't work if there is no grid power: 1.1 The extra energy, beyond the self-consumption, is lost, both in the case that it is not fed into the grid (inverter with limit) and in the case that it is fed in (e.g. plug-and-

play).
1.2 | The extra energy, in addition to self-consumption, is fed into the grid (on-grid inverter) and is remunerated in various ways by the local operator (in Italy: SSP contract with GSE).
1.3 | The extra energy, beyond the self-consumption, is stored in a local storage, to be used in the hours without production. (In Italy: solar energy is available, simplifying, 6 hours in summer, 4 hours in winter).

2 UPS (uninterruptible power source) systems, usually off-grid, can replace the grid in the event of a blackout. Load limited to the power of the inverter, which, in the presence of inductive loads (motors), must be sized for the starting point (at least triple the power). 2.1 UPS inverters manage three energy sources - Solar, Grid and Battery - with various strategies. The extra solar energy is stored in the battery or lost.

3 Independent systems, not connected to the grid (off-grid), always with loads limited to the power of the inverter:
3.1 | Without storage: the energy produced is used immediately, for example, crop irrigation.
3.2 | With storage, to ensure 24/7 services, e.g. street lighting and isolated houses.
We will mainly deal with on-grid and UPS systems, among which it is often difficult to choose. For autonomous systems let's just say that they have the advantage, while complying with the standards, of not being subjected to the constraints of the distribution company, but must be sized for power peaks and equipped with adequate storage. However, it is advisable to provide other sources of energy and backup, for example, a wind/hydraulic turbine and/or a fuel generator, as it is not possible to use the grid in the event of low production, such as with cloudy skies for several days.
Note: some hybrid inverters manage two AC outputs (230V): the first for essential services (solar, battery) and the second for heavier loads (solar, grid).

Projects
- project B: module 800 / 1000 / 1200 Wp on grid
- project C: module 800Wp, with limit
- project D: adding storage to C (1200 Wh)
- project E: UPS hybrid inverter 6200W + storage, off-grid/grid tie.

This is a work in progress, with continuous updates. The last version of this document is in the repository https://github.com/msillano/DIY-photovoltaic-smart

Disclaimer
This article is for informational purposes, and is true and accurate to the best of the Author's knowledge, but may contain inadvertent errors or inaccuracies: it is provided "as is", without warranties of any kind, implicit or explicit.

The practical execution of the projects and the sizing calculations of the components and of the electrical connection cables must in any case always be carried out, verified and validated by specialized, competent and qualified technical personnel, in full compliance with all current electrical and safety regulations , which vary according to the country, therefore the Author is not responsible for direct or indirect accidental damages caused by the use of the information provided.

Note on WiFi
I don't want to use proprietary clouds, and therefore neither remote control WiFi APPs, apart from Tuya (https://www.tuya.com/) and the smartLife (https://ismartlife.me/) APP.

Already deciding to use Tuya and its cloud as the IOT environment of choice, and as the basis for the development of the TuyaDAEMON (https://github.com/msillano/tuyaDAEMON) IOT framework was a difficult decision, justified by the high level of security, excellent performance, and the peculiar commercial position of Tuya as third-party service provider, a position that guarantees end users - see, for further information, 'why TuyaDAEMON' (https://github.com/msillano/tuyaDAEMON/wiki/why-tuyaDAEMON-%3F) (in Italian, 'perché TuyaDAEMON'). (https://github.com/msillano/tuyaDAEMON/blob/main/perch%C3%A9-tuyaDEAMON.pdf)

The basic remote control and automation operations, where available, are therefore those native to Tuya and smartLife, including voice commands (Google or Alexa) sufficient in most cases - they are the best available on the market. If you want higher performance, such as integration with other devices, collected data processing, advanced logic, and custom user interface, then you can use TuyaDAEMON. (https://github.com/msillano/tuyaDAEMON)

This leads to the preference for Tuya-compatible devices when choosing smart components.

Note on prices
The Author is not sponsored or affiliated in any way to any company: the choices are made only on the basis of personal conviction. I have tried to favor international suppliers for two reasons:
✔ Global availability, to be able to carry out these projects anywhere in the world.
✔ A good quality/price ratio, which can serve as a comparison.

The prices presented are for reference only: they are the amount I found or paid to the indicated supplier (inclusive of taxes and EU shipping, unless indicated otherwise – August-2022 March

2023).
Prices can obviously vary (especially in this period and in the photovoltaic sector). In addition, state subsidies have inflated prices, at least in Italy.
Sometimes I refer to Italian products or to the UE-Italian regulatory situation, which I know best, but this is always clearly highlighted.
Before making important purchases, carefully select both the product and the supplier.

# Analyses

Importance of storage

As starting data, let's consider a 1 kWp solar system ‘on-grid’: in optimal conditions, it will produce 1500 kWh/year (Rome, see simulation), i.e. on average 125 kWh/month and 4.1 kWh/day.
Therefore simplifying a lot, during a summer day, from 9 to 15 (6 hours), 670 W (4.1/6) are available. For 2 kWp we double this value.
In the figure, we have the consumption (5.80 kWh) for 8 July 2022 in green and the schematic PV production in yellow. Self-consumption is represented by the yellow+green area. Let's look at various scenarios:
A) 1 kWp solar system
Solar: | 4.1 kWh | (equal to 69 %)
Self-consumption: | 0.7 kWh | (equal to 12 %)
If a battery stores the extra energy (yellow: 3.4 kWh) and gives it back over the following 18 hours, with 80% efficiency, we have 2.4 kWh.
In total: | 0.7 + 2.4 =3.1 kWh | (53 %)
B) 2 kWp solar system
(in the figure the yellow band would have double height):
Solar: | 8.0 kWh | (equal to 138 %)
Self-consumption: | 0.7 kWh | (equal to 12 %)
If a battery stores unused energy (7.3 kWh) and returns it over the following 18 hours, with 80% efficiency we have 5.8 kWh.
In total: | 0.7 + 5.8 = 6.5 kWh | 100% + residual 0.7 kWh

note: Consumption peaks exceeding the inverter capacity (1000 or 2000 W), which always absorbs power from the grid, are not considered in the estimations.
Conclusion:
On the day under review, the presence of a battery drives self-consumption from 12% to 53% (1 kWp) or 100% (2 kWp).

Actual consumption in a 4 month interval
In the following table, we have:
kWh(month): consumption in the month, from the load-curves by the grid operator 'e-distribuzione' avg24: average daily consumption = kWh(month)/30(31)
max24: maximum daily consumption in the month (from 'e-distribution' load curves)
min24: minimum daily consumption in the month (from 'e-distribution' load curves)
kWp (100%): power for a photovoltaic system (theoretical): 1 kWp = 125 kWh/month
month | kWh (month) | avg24 | max24 | min24 | kWp (100%)
June 2022 | 175,45 | 5,85 | 21,63 | 1,22 | 1,4
July 2022 | 202,08 | 6,52 | 30,92 | 4,28 | 1,6
August 2022 | 320,63 | 10,32 | 16,81 | 5,39 | 2,6
Sept. 2022 | 170,33 | 5,67 | 7,6 | 2,58 | 1,4
average | 217,1225 | 7,2 | | | 1,7

Let's do a more detailed simulation of self-consumption with storage:
1. for each month we use the PVGIS data (kWh PVGIS/m) multiplied by 0.8 (battery efficiency) to evaluate the available average daily solar energy (kWh PV/d)
2. from the daily consumption (the 'e-distribuzione' APP allows the CSV export of the data) we subtract the self-consumption (PV/d). What remains, added up, is kWh pay/month that must be provided by the grid
3. let's look at three cases: 1kWp, 2kWp, and 3kWp

These values are an optimistic estimate for several reasons:
- The PVGIS considers the system losses equal to 14%. In a small plant, they can be greater.
- It is assumed that the batteries can accumulate all the daily energy (3.86...14.4 kWh)
- Consumption peaks have been neglected: i.e. consumption above 1000/2000/3000 Watts, which are always taken from the grid.

The estimate is instead pessimistic because:
- The data refer to habitual consumption, not optimized to increase self-consumption
- Each day is isolated, without calculating any remaining energy from the previous day.

It can be seen how the increase from 1000 to 2000 Wp brings the savings from 50% to 80% (+ 30 %), while the increase from 2000 WP to 3000 Wp brings an advantage of only 13%. This is also reflected in amortization (assumptions: consumption 2800 kWh/year, PV+storage cost 2000 €/kWp, energy cost: 41.51 c€/kWh):
1000 W (self-consumption = 2800 * 49% = 1370 kWh) amortization 5 years 5 months
2000 W (self-consumption = 2800 * 79% = 2200 kWh) amortization 6 years 3 months
3000 W (self-consumption = 2800 * 93% = 2600 kWh) amortization 7 years 9 months (calculations with solar/payback-photovoltaic); (https://www.sunearthtools.com/it/solar/payback-photovoltaic.php)
3 kWp is probably the right size for an ‘on-grid’ system, but I chose to build a 2 kWp system because:
- I believe that careful management of electrical devices can increase self-consumption
- Most important: I have no space for panels for 3 kWp!
month | energy grid | PVGIS/m | PV/d | pay/m | % saving | avg
PV system 1kWp
June 2022 | 175,45 | 170,85 | 4,53 | 78,67 | 55,2% 48,94%
July 2022 | 202,08 | 186,41 | 4,8 | 135,22 | 33,1%
August 2022 | 320,64 | 178,25 | 4,59 | 188,3 | 41,3%
Sept. 2922 | 170,33 | 145,06 | 3,86 | 57,52 | 66,2%
PV system 2kWp
175,45 | 341,7 | 9,06 | 36,74 | 79,1% 79,44%
202,08 | 372,82 | 9,6 | 76,72 | 62,0%
| 320,64 | 356,5 | 9,18 | 74,76 | 76,7%
Sept. 2922 | 170,33 | 290,12 | 7,72 | 0 | 100,0%
PV system 3kWp
175,45 | 512,55 | 13,59 | 13,83 | 92,1% 93,38%
| 202,08 | 559,23 | 14,4 | 34,09 | 83,1%
| 320,64 | 534,75 | 13,77 | 5,54 | 98,3%
Sept. 2922 | 170,33 | 435,18 | 11,58 | 0 | 100,0%

June 2022
July 2022
August 2022

June 2022
July 2022
August 2022 note: Italy - exchange on site (‘Scambio Sul Posto’: SSP)

In Italy, the European 'Conto Energia' (remuneration by the operator) is now (2022) implemented through the 'Scambio sul Posto' (https://www.gse.it/servizi-per-te/fotovoltaico/scambio-sul-posto) (or SSP) contracts with GSE, (https://www.gse.it/) whatever the supplier company is.
It would seem that the SSP could replace storage, but in reality, for the user, this is not exactly the case.

Let's simplify by considering the SSP as a virtual battery, with a yield between 99% and 60%, yield essentially determined by the spread between the energy purchase and sale prices (60% can be considered an extreme case: see article). (https://www.vaielettrico.it/scambio-sul-posto-ecco-i-conti-della-batteria-virtuale/)
Let's consider July 8, 2022, with a consumption of 5.8 kWh (see above for details), and the worst case (60%) to highlight the problems:

### 2 kWp solar system with SSP, we have:

Solar production: | 8.0 kWh | (equal to 138 %)
Self-consumption: | 0.7 kWh | (equal to 12 %)
If we transfer the unconsumed energy (7.3 kWh) to the grid, this corresponds (from GSE calculations) to 4.4 kWh (at 60%) of consumption:
In total 2 kWp + SPP gives: 0.7 + 4.4 = 5.1 kWh (equal to 87 %)
Be careful though:
- The electricity bill will be reduced by self-consumption only: 5.8 -0.7 = 5.1 kWh.
- The bill must be paid immediately for the total (5.1 kWh) and will then be partially refunded by bank transfer from the GSE.
- Refunds will repay the value of 4.4 kWh, i.e. net we only pay for 5.1 – 4.4 = 0.7 kWh.
- However, we pay in full (i.e. on 5.1 kWh) both MTC (0.015 €/kWh) and taxes: VAT (10%) and excise duties (0.022 €/kWh), subsequently compensated only in part by the 'unit exchange fee annual flat rate' (https://lamiacasaelettrica.com/quanto-paga-il-gse-lenergia-immessa-in-rete/) (5.08 c€/ kWh) calculated in the SSP.
- GSE management expenditure: up to 3 kWp, free; from 3 kWp to 20 kWp €30/year.
- Cost of production meter: about €20/year
- Any surplus kWh can be valued by GSE for a value close to the PUN (Unique National Price, (https://www.mercatoelettrico.org/it/) variable: see intro), (https://www.enel.it/it/supporto/faq/cos-e-il-pun) also taxed as 'other income'. (https://www.investireoggi.it/fisco/impianto-fotovoltaico-energia-eccedente-nel-modello-730-istruzioni/)
Even in the SSP case, it can be seen how important it is to increase self-consumption, i.e. how appropriate the use of storage is.
But if high percentages of self-consumption must be reached, then the SSP becomes less attractive: the only advantage remains the summer/winter exchange, which cannot be managed with local batteries.
To comply with the regulatory constraints it is also necessary:
✔ | Use of devices (all) approved according to CEI 0-21 (with a protectionist effect)
✔ | A qualified installer for installation
✔ | A designer registered for the practice of connection to the national grid

note: Thermal storage

An interesting possibility to increase self-consumption is to use a pre-existing electric storage water heater (the most common) as a (thermal) energy tank:

- The first rule is to use photovoltaic energy as much as possible to heat the water.
- An electric water heater has a high consumption (e.g. Ariston 80L, 1500W) to have rapid heating. By reducing the supplied power (e.g. with a dimmer) a longer heating period is obtained, but a greater self-consumption of solar energy. It is

also possible to think of dynamic modulation of the power, based on the availability of energy.
- If other household appliances (dishwasher, washing machine...) use the hot water from the water heater instead of cold water, there is further saving: the household appliance consumes less electricity to bring the water to the required temperature, and so the energy produced in the hours of sunshine can be used to reduce consumption at different times.

The energy needed to heat an 80-liter boiler, from 15° to 60° is equal to 4.2 kWh, an important fraction of daily consumption.

In formula: | E=

L∗ΔT
860 [kWh]
where L is liters and ΔT the temperature difference in °C.

✔ This obviously applies to standard storage water heaters, not to heat pumps or gas water heaters.
✔ The boiler thermostat temperature is an important factor: in summer 40° and in winter 60° are usual values.
✔ If the water heater consumes 1300W, it will take 3h:38m to heat up to 60°.
✔ It is appropriate to give low priority to the water heater, i.e. turn it on only when there is photovoltaic energy available: there are various commercial solutions (https://www.4-noks.com/shop/solare-fotovoltaico/power-reducer-sa/) for this purpose. ✔ For a DIY 'modding' project of a standard storage water heater to make it 'smart' with tuyaDAEMON. See (under development).


Power Dimmer:

2000/4000W High Power Thyristor (https://www.aliexpress.com/item/1005002565441317.html) 2,71 / 6,86 €

Rows of solar panels

If the panels are not coplanar (case of the pitched roof) and if the panels are arranged in several rows, the problem of shadows arises between rows and the need for spacing increases the occupied surface (filling factor).


We have, in the flat case - see the figure with the side schematic view of 2 rows of photoelectric panels:

L: panel length
θ: panel angle (slope) | h=L⋅sin (θ)

To have no shadows the distance between rows (s) must be greater than or equal to d, with α: minimum height of the sun (arrow in the figure):
| d =h⋅cot(α)=

h
tan (α)
The formulas are more complex in the case of sloping terrain. (https://www.ediltecnico.it/85611/come-calcolare-la-distanza-minima-di-installazione-di-file-di-pannelli-fotovoltaici/)
Installation of solar panels
For the reasons already seen in part A, (https://github.com/msillano/DIY-photovoltaic-smart/blob/main/fotovoltaico-part-A-v2-en.pdf) also in these projects we use the flexible panels model RG-MN-100 (https://it.aliexpress.com/item/4001199723442.html)
| • power 100 Wp,
| • dimensions 1050 x 530 x 2.5 mm,
| • weight 1,9 kg,
| • open circuit voltage 19,2 V,
| • short circuit current 6,87 A
| • cables: 90 cm x 2.5 mm²
| • link for more information. (https://www.alibaba.com/product-detail/save-electricity-durable-16V-100W-mono_62206562525.html)

Based on the characteristics of the panels and the inverter (or controller) we can establish the number of series panels (called also strings: the voltages are added) and the number of strings (equal to each other) in parallel (the currents are added).
Note: in the temperature range -10°C.. + 70°C both Voc (21.31V… 16.5
V) and Icc (6.79 A… 6.96 A) vary.

Examples:
With these panels, the 5P2S arrangement (1000 Wp) provides 38.46V (max 42.62V) and 34.35A (max 34.8A), compatible with the inverter chosen in project C (26-45V, max 40A ).

8 connected 2P4S panels (800 Wp, for battery, project D)
- open circuit voltage. 76.8 V (max 85,24 V)
- short circuit current: 13.74 A (max 14 A)

For the project E, we have the range:
9 connected 9S panels (900 Wp):
- open circuit voltage. 172.8 V (max 191.79 V)
- short circuit current: 7.87 A (max 7 A)
60 connected 3P20S panels (6000 Wp):
- open circuit voltage. 384 V (max 426.2 V)
- short circuit current: 20,61 A (max 21 A)

Different connection schemes are possible, to make the connections as short and homogeneous as possible. Example: I have chosen the following scheme for project C (5P2S):

Each panel in one row is in series with the corresponding panel

in the other row using panel terminals (90 cm).

5 black extension cords and 5 red extension cords, of variable length, 2.5 mm²

In the positive connections, there are 5 optional 10 A blocking diodes (the bypass diodes are already present in the junction box of the panels).

The extensions terminate in two watertight boxes
2 x 6 mounted on the structure of the panels from which two larger cables depart for the inverter.

Obviously, it is better to have cables as short as possible.

Only if the panels are very close to the inverter, can the junction boxes are omitted and the 10 cables sent directly to the inverter.

Panel mounting accessories For the 10 extension cords

20 x PV connectors (https://it.aliexpress.com/item/1005003178551935.html) | 8,94 €

For each string of 2 panels, one blocking diode (they could be replaced with fuses):

5 x diode 10A (https://it.aliexpress.com/item/1005004521273762.html) for PV | 18,6 €

Cables for PV (e.g PV1-F), accessories
- in tinned copper (or aluminum for outdoors)
- double insulation in XLPE (no PVC)
- temperatures -40°/+90° (+120°)
- duration: 25 years
- section min > 0.25 mm²
/A


PV cable (https://it.aliexpress.com/item/1005004709208928.html) (PV1-F)

for panel extensions (short, 7A): 1 x AWG13 – 2,5 mm²
, 10 m (black) | 17.65 €
1 x AWG13 – 2,5 mm²
, 5 m (red) | 10.53 €

from junction to inverter
diameter to be calculated (https://www.oppo.it/calcoli/cavi/calcolo_sezione_cavo.php) case by case as a function of distance and current. Use
- 40V voltage (e.g.)
- 1.25 coefficient for the powers (1000 Wp => 1250W).
- loss < 1% (i.e. 0.4V).
See also the link. (http://www.cvsperoni.it/index.php/collegamento-dellimpianto-solare-alla-linea-elettrica/)

Example: 5P2S (7*5 = 35A max):
AWG7 - 10 mm² (https://it.aliexpress.com/item/1005003408748449.html)
, 4 m (red + black, indicative) 45,13 €

The string parallel joint solutions
- Use mammoths or clamps
- Terminate the cables with cable lugs.
- Use a special Solar Connector 2T … 6T (https://www.aliexpress.com/item/1005005009551213.html)
- Use the DC field switchgear (see Project E)

For instance:

DIN terminals (https://it.aliexpress.com/item/1005003698775638.html) 2x7 | 6,92 €
5 x 5,3 mm => 2.5...6 mm²
cable
2 x 7,5 mm => 10...25 mm²
cable
Bare terminal 7 fori (https://it.aliexpress.com/item/32845005334.html) | 2,37 €

Cable lugs (https://it.aliexpress.com/item/4000118034554.html) (20 pz):
SC4-6 | (12AWG) | 1,50 €
SC10-6 | (7AWG) | 2,50 €

If the cables do not reach the inverter box, always use waterproof junction boxes:

2 x 6 way junction box (https://it.aliexpress.com/item/1005003639125997.html) | 10,32 €
Total mounting accessories for 5P2S panels: | 97 €

note: it can be considered that the use of mini-inverters (such as those used in the plug-and-play project, (https://github.com/msillano/DIY-photovoltaic-smart/blob/main/fotovoltaico-part-A-v2-en.pdf) or the SG-1200W-Mobile WIFI) (https://it.aliexpress.com/item/1005004388329667.html) requires fewer accessories, simplifies assembly and ultimately reduces costs.
Unfortunately, these inverters are not equipped with the 'LIMIT' function and are therefore not suitable for the C project.

DIY: Panel supports
A well-oriented pitched roof is the simplest case. There are many types of hardware to ensure, in various cases (tiles, corrugated, etc.), easy assembly of the solar panels in adherence to the groundwater (in Italy it is required by standards) without compromising the tightness of the roof. However, the costs of scaffolding, labor, etc. must be considered.

The case of terraces and flat roofs is more technically complicated: I found the space for the solar panels using the flat roof of a box (see satellite image from PVWATTS, (https://pvwatts.nrel.gov/index.php) plus protractor). (https://www.ginifab.com/feeds/angle_measurement/online_protractor.it.php) It is not optimal (Azimuth 45°, shadows from buildings) but it is the only usable place available. Given the low height of the box, safety works (railings) are not necessary.

However, a structure is needed to position the solar panels at the right angle, robust enough and stable in the winds.

The type of system conditions the orientation of the panels.


If the energy fed into the grid is remunerated in some way (Italy: SSP), the goal is to maximize the annual production, and PVGIS automatically provides the optimal values of 'slope' and 'azimuth'.
If, the energy is not fed into the grid ('limit' or 'off grid' inverter), due to storage limitations
- summer energy cannot be accumulated for consumption in winter - the aim is to maximize winter production: the optimal 'slope' must be found by trial and error with PVGIS.
In the present case, the azimuth is imposed by the existing roof (45°). By varying the slope ( 1 kWp ):
Slope | Year | July | December | July/Dec kWh | % | kWh | % | kWh | %
0° | 1372 | 91% | 197,29 | 99% | 41,31 | 56% | 4,78
5° | 1413 | 94% | 198,43 | 100% | 46,35 | 63% | 4,28
10° | 1446 | 96% | 198,45 | 100% | 51,1 | 69% | 3,88
15° | 1472 | 98% | 197,79 | 100% | 55,45 | 75% | 3,57
20° | 1491 | 99% | 196,42 | 99% | 59,35 | 80% | 3,31
25° | 1502 | 100% | 193,89 | 98% | 62,78 | 85% | 3,09
30° | 1507 | 100% | 191,21 | 96% | 65,76 | 89% | 2,91
35° | 1504 | 100% | 187,63 | 95% | 68,28 | 93% | 2,75
40° | 1492 | 99% | 182,78 | 92% | 70,35 | 95% | 2,60
45° | 1474 | 98% | 177,25 | 89% | 71,92 | 97% | 2,46
50° | 1451 | 96% | 171,86 | 87% | 73,01 | 99% | 2,35
55° | 1418 | 94% | 164,87 | 83% | 73,64 | 100% | 2,24
60° | 1376 | 91% | 157,12 | 79% | 73,79 | 100% | 2,13
65° | 1329 | 88% | 148,83 | 75% | 73,47 | 100% | 2,03
70° | 1274 | 85% | 139,99 | 71% | 72,7 | 99% | 1,93
75° | 1213 | 80% | 130,42 | 66% | 71,46 | 97% | 1,83
80° | 1146 | 76% | 119,73 | 60% | 69,77 | 95% | 1,72
85° | 1073 | 71% | 109,24 | 55% | 67,64 | 92% | 1,62
90° | 995 | 66% | 98,6 | 50% | 65,07 | 88% | 1,52

December 21st at 12:00 = 25°. December 21st at 14:00 = 20°. December 21st at 15:00 = 12° .; Energy vs slope; Year December July; slope; d@Sun 20°; d@Sun 12°

More immediate by looking at a graph:

The SunHeartTools (https://www.sunearthtools.com/dp/tools/pos_sun.php) site provides, for a given location, the
height of the sun at each time.

Now let's calculate the minimum distance between rows, with
a panel height of 105 cm:

The distances between rows are all greater than 2 meters, really high. I can choose 50°

For verification, this is the
irradiation of an (average)
day in December, (from
PVGIS, slope: 50°, Azimuth:

Clear-sky does not account
for atmospheric absorptions
for particles and clouds.

Solution 1: (without grid entry)
The fixed structure for rows of solar panels is made up of iron ribs and cross-currents to which the panels are fixed. Each rib has the support for each row of panels, with an (optional) leg that can be anchored as needed.
The basic values, for a system without feeding into the grid, are: 5x2 panels (1000 Wp), slope 50°, row distance 225 cm, 3 ribs.

Structure characteristics 5x2 (1000 W):

1. The structure is made up of L-shaped iron profiles, 35x35 mm perforated - shelf profiles -easily available everywhere.
2. Each rib is made up of two or more supports connected by spacers: the angle (slope) is defined in the design phase, the distance between rows in the assembly phase. The supports are fully welded for greater strength.
3. The ribs are connected to each other by 2 or 3 beams (wood, aluminum, galvanized steel sheet, etc.) bolted during assembly.
4. Without the vertical leg (S_leg = 0) the supports can simply be placed on the floor or fixed vertically on a wall (see example).


When assembling always add a safety system, e.g. lateral anchors to railings or walls or steel cables, to avoid movement and overturning.

All the supports have been calculated with the same parametric OpenSCAD (https://openscad.org/) project: the user can change many values in the file and both the drawings and the parts list is automatically updated. Download here. (https://github.com/msillano/DIY-photovoltaic-smart/blob/main/extra/FV-support.03.scad)

The entire structure for 1000 W requires 3 ribs with 2 supports each, 3 spacers and additionally 3 stringers for each row of 5 panels. (Protractor is MB-ruler). (http://www.markus-bader.de/MB-Ruler/index.php)

The OpenSCAD parametric project (https://github.com/msillano/DIY-photovoltaic-smart/blob/main/extra/FV-support.03.scad) also provides a complete parts list with the dimensions, and the total (net) of the L-profile needed:

Parameters:
string = 5x2
PV panel = 1050x530 mm

distance = 2250 mm
feet = 250 mm

ECHO: "Panels 5X2, slope: 50°" ECHO: "Footprint: 3702.43 x 2656 mm" ECHO:
ECHO: "6 x supports:"
ECHO: " base: 1052 mm"
ECHO: " Hbar: 720 mm"
ECHO: " Vbar: 840 mm"
ECHO:
ECHO: "3 x spacer: "
ECHO: " length: 2411.86 mm" ECHO:
ECHO: "6 x currents:"
ECHO: " length: 2656 mm"
ECHO:
ECHO: "8/12 x bolts M8x15 " ECHO: "60 x wood screws M 4x30" ECHO:
ECHO: "Total L: 22907.6 mm"


Solution 2: (without grid entry) Alternative to solution 1, with the panels (2x5) located in the same plane.
The parameters are similar: slope 50°, but with 5x1 panels using the (virtual) size 2100x530, 3 ribs.

note: given the important dimensions, the structure can be strengthened:
- coupling the profiles to form a U.
- adding an intermediate vertical element
- adding a diagonal rear element
- adding a square plate, with holes at the corners, to each rib-beams joint

Parameters:
string = 5x1
PV panel = 2100x530 mm
slope | = 50°
feet | = 0

ECHO: "Panels 5X1, slope: 50°" ECHO: "Footprint: 1451.14 x 2656 mm" ECHO:
ECHO: "3 x supports:"
ECHO: " base: 2102 mm"
ECHO: " Hbar: 1320 mm"
ECHO: " Vbar: 1323.18 mm"
ECHO:
ECHO: "5 x currents:"
ECHO: " length: 2656 mm"
ECHO:
ECHO: "60 x wood screws M 4x30" ECHO:
ECHO: "Total L: 14235.5 mm"

Solution 3: (on grid)


In this case, it is possible to use a very small slope (12°) with few losses compared to the annual maximum (97%) obtaining a compact structure adhering to the floor.
The basic values are: 5x2 panels (1000 Wp), slope 12°, rows distance 70 cm, 2 ribs.

Parameters:
string = 5x2
PV panel = 1050x530 mm

slope = 12°
distance = 700 mm
feet = 250 mm

ECHO: "Panels 5X2, slope: 12°" ECHO: "Footprint: 2861.94 x 2662 mm" ECHO: "4 x supports:"
ECHO: " base: 1054 mm"
ECHO: " Hbar: 840 mm"
ECHO: " Vbar: 400 mm"
ECHO:
ECHO: "2 x spacer: "
ECHO: " length: 1071.39 mm" ECHO:
ECHO: "6 x currents:"
ECHO: " length: 2662 mm"
ECHO:
ECHO: "8/12 x bolts M8x15 " ECHO: "60 x wood screws M 4x30" ECHO:
ECHO: "Total L: 11318.8 mm"

Solution 4: Plug and Play 300W

This example shows how, with the appropriate parameters, this OpenScad project (https://github.com/msillano/DIY-photovoltaic-smart/blob/main/extra/FV-support.03.scad) can also define a horizontal support to be fixed with plugs for wall, slope 72° (S_slope = 18), Footprint: 507 x 3158

Construction notes

- However they are arranged, there is always a 1 mm gap in the joint of the triangular supports: if required insert a shim (washer) before welding.
- Use 2 or 3 M8x15 bolts to fix the horizontal spacers.
- Flexible panels can be directly fixed with screws if the currents are made of wood or aluminum.
- With rigid panels, a strong profile in aluminum or galvanized steel for PV (https://www.teknomega.it/fissaggio-pannelli-fotovoltaici/morsetti-per-pannello/installazione-delle-ganasce.kl) can be used directly as a current.
- If there are height constraints, do not use the legs (S_leg = 0) and adequately ballast the profiles laid on the floor (20/100 Kg/m2).
- Otherwise (in the case of a terrace with balustrades) each leg can use an umbrella base (https://www.orizzonteshop.it/products/mirada-base-plastica-per-ombrellone-effetto-rattan-ean-8002936045911) ( 7,50 €) ballasted with water or sand, to which the vertical support is bolted.
- Pay attention to roof slopes and avoid standing water. Use an insulating sheet under the supports.

Note: for an example of industrial supports with all the mounting details see Cosmogas, manuale di installazione pannelli solari (https://www.cosmogas.com/sites/default/files/docs_certificati/HARMONY%20e%20SOLARPLUS_ITA_62403459.pdf) (in italian).
Lightning protection
There are two types of lightning-related problems
Direct damage, caused by lightning striking the panels.
Catastrophic, damages are very important, and the only solution is an adequate independent lightning protection system (LPS). Generally only in the case of isolated buildings or solar panels mounted directly on the ground.
Indirect damage, caused by the electromagnetic field of a nearby lightning strike.
Protection is provided by surge protectors (SPD) placed at strategic points: at the AC input, at the DC output for the inverter, and, if a cable exceeds 10m, at both ends of the cable.

Usually, it is not advisable to connect the metal structures of solar panels to the ground: it seems that this increases the probability that they will be struck by lightning.

Support materials x 10 PV panels (1’000 W)
12 x Metal upright 3,5 x 3,5x200 cm (https://www.leroymerlin.it/prodotti/ordine-e-sistemazione/organizzare-gli-ambienti-di-servizio/scaffali/tutti-gli-scaffali-in-metallo-componibili/montante-in-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) grey/silver (7€) | 84 €
6 x Wood 30x40 x 3000 mm ( indicative: 12 €) | 72 €
or:
6 x Aluminum 30x30x2 x 3000 (indicative: 20 €) | 120 €
or:
6 x Galvanized profile for PV 41x21 x 3000 (indicative: 23 €) | 138 €

..Screws and bolts, paint, welding, ballast and/or anchors, steel safety cable with clamps, wall
plugs (indicative) | 30 €
Structure cost for 10 PV panels: | 200--280 €.

note: many of these materials are bulky and heavy: it is better to buy them on the spot. The prices and links provided are just an example. Find the best equivalent local offer.

# Photovoltaic over 350W

Commercial example: 600W (800 ?) grid tie (https://it.aliexpress.com/item/1005004892178189.html)

- 4 x panels 200Wp (1140x700 mm) 800 W (!) (2P2S)
- inverter 600 W(!) (note: model without WiFi)
- 2,5 m DC cable, 2,5 mm²
- 5 m AC cable
- mounting accessories
Cost | 869 €
Cost per kWp | 1.448 €


Commercial example Italy: 1,5kWp photovoltaic kit (https://www.lacasadelsolestore.com/index.php?id_product=213&controller=product) WITH LIMIT – CEI 0-21

- 4 * monocrystalline photovoltaic panels 380/375Wp HANOVER Solar / MUNCHEN Solar (1760 x 1006 x 35 mm)
- Inverter Zucchetti CEI 0-21 1100Wp (!) ZCS 1100TL-V3
- 10mt red photovoltaic cable 4mmq
- 10mt black photovoltaic cable 4mmq
- 2 pairs of MC4 connectors
- Input sensor for LIMIT input
Cost | 1379 € + shipping
Cost per kWp | 919 €

Commercial example Italy: KFV30 photovoltaic kit 3 kW (https://efficasa.it/2233-kit-fotovoltaico-3-kw-impianto-solare-completo-con-inverter-strutture-e-accessori-240.html)

- 410 Wp Monocrystalline Modules Hyundai HiE-S410VG; 25-year product and performance guarantee (number ??)
- Inverter AZZURRO ZCS-3000TLM-WS, 3 kW
- MC4 type male and female Amphenol fittings - 4 sq. mm
- Support and fastening structures
Cost: | 4400 €
with installation and paperwork 7400 €

Cost per kWp: 1467 € ( 2470 €)

Commercial example Italy: 2000 Wp photovoltaic kit (https://www.ecorete.it/_fotovoltaico-chiavi-in-mano/KIT-FOTOVOLTAICO-2KW-INSTALLATO.php) including installation
- 10* 200W CANADIAN panels
- AROS 2600 Wp inverter (certified)
- DC panel
- AC switchboard
- Inclined roof supports (screws, cables)
- installation
- drafting of an 'energy account' application
Cost: | 5148 €
Cost per kWp | 2574 €

Commercial example Italy: 1.5kWp hybrid photovoltaic KIT with 3kW 24V PWM inverter and 2 AGM 200Ah batteries (https://www.lacasadelsolestore.com/index.php?id_product=237&controller=product) (island).

- 4 x MUNCHEN Solar 375Wp photovoltaic panels
- 3kW inverter with PWM charge controller
- 2 * 12V 200Ah long-life AGM batteries. Total 4800Wh (useful 2400 Wh)
Cost: | 2209 €
Cost per kWp | 1472 €

note: as a starting point for a broader analysis of the photovoltaic kits available on the Italian market, see also https://www.fotovoltaiconorditalia.it/idee/costo-kit-fotovoltaico-kilowatt.

# DIY project B: 800 / 1000 / 1200 Wp module

From the HW point of view, it is similar to plug-and-play, with the difference that, if a threshold is exceeded (Italy 350 W), the compensation mechanisms active in the various countries must be activated (in Italy 'scambio il posto' or SSP).
The energy produced is either consumed locally (self-consumption) or fed into the grid and accounted for by a meter.
PROS:
✔ HW without storage, very simple and cheap.
✔ Can greatly reduce bills (Italy SSP analysis: see above)
✔ Compensates summer/winter, which is impossible with storage.

COS:
✗ Limited by contractual power (in Italy: 3.3 kW or 6.6 kW for homes).
✗ SSP is not as convenient for the user as self-consumption (see SSP analysis)
✗ Bureaucratic complexity (https://impianti.tech/fotovoltaico-guida-alliter-semplificato-di-connessione/) and delays in updating meters (Italy: over 3 months)
✗ Numerous constraints on materials and inverters (certified) and on the installing company (authorized).

These projects send the extra energy to the grid: they must therefore be used with a 'Conto Energia' with the distributor. They must meet all the specifications required by the standards in force and by the counterparty (they vary depending on the country and the distributor company), and must also be installed by qualified firms. It doesn't seem very suitable for DIY. (https://efficasa.it/59-pratiche-e-incentivi) Here we present three hypotheses, substantially similar.


For safety it is necessary, in the DC circuit:
- surge protection (for lightning)
- panel switch. (if necessary)

In the AC circuit:
- a switch with protection to disconnect the inverter from the grid

DC protections: between the panels and the inverter (see diagram)

CHYT DC Surge protection 20-40 KA 600V (https://it.aliexpress.com/item/4001043607240.html) | 12 €

If the inverter is mounted on the panels, the protection can be inserted on the AC side
CHYT AC Surge protection (https://it.aliexpress.com/item/1005003973886758.html) | 11,35 €
Watertight box DIN CHYT (https://www.aliexpress.com/item/1005004300793604.html) | 8,04 €
2 modules

AC protections: between the inverter and the 220V bus (see diagram)

2P 63A TUYA APP WiFi Smart Energy Meter (https://it.aliexpress.com/item/1005002361164427.html) OPWT-63 € 33

This meter combines the functions of breacker, protection and power meter.
It can provide information about the energy produced by the inverter.
Measurements are accessible via WiFi (Tuya compatible).


Disconnector AC for a single module
EARU breaker (https://www.aliexpress.com/item/4000917622193.html) DZ47 2P 10A | 7,07 €

As an alternative to the OPWT -63 meter

Inverter on grid

Inverter SG-1200W-Mobile WIFI (https://it.aliexpress.com/item/1005004388329667.html)

Max input: 60V, startup 20 V ( max 3 panels) Max input: 4*10A, 4*300W
Output: 1150 W (220V, 5A)
WiFi smartLife compatible
Cost: | 250.02 €


Very compact and easy to assemble, it includes the compatible Tuya WiFi function. From the same series as the one used for the plug-and-play A2 project. (https://github.com/msillano/DIY-photovoltaic-smart/blob/main/fotovoltaico-part-A-v2-en.pdf)
Works with both 4*2 panels (4P2S, 800W) and 4*3 panels (4P3S, 1200W) Modular, up to 8 units (9,600 W) can be connected in series.

ZCS Zucchetti Azzurro 1Ph 1100TL-WS (https://www.solarenergypoint.it/shop/zcs-azzurro-zs1-1100tl-ws%E2%80%93inverter-monofase-1mppt-1100w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)

Input 80V-450V. Max 10A (datasheet) (https://www.zcsazzurro.com/uploads/documetazione/User-manual-1PH-1100TL-3300TL-V3-it.pdf) (10 pannels in series) Output 1000 W
With MOV disconnector and unloaders
Custom WiFi (not SmartLife compatible)
RS485 channel
CEI0-21 certificate (Italy): YES
Cost: | 442,63 € + VAT + transport

The inverters of the Zucchetti Azzurro series are used by ENEL in commercial photovoltaic kits in Italy.
This inverter uses the connection of solar panels in series, saving connectors and diodes, but with high DC voltages and greater vulnerability to shadows.

Cost summary 800 / 1000 / 1200 Wp

item | PV [kWp]
800 | 1000 | 1200
8/10/12 PV panels RG-MN-100 | 692,8 | 866 | 1039,2
Inverter SG-1200W / ZCS 1100 | 250 | 480 | 250
Meter WiFi OPWT 63 (optional) | 33 | 33 | 33
panels installation (see later) | 180 | 200 | 220
Surge protector + box | 20 | 20 | 20
Mounting accessories (variable) | 50 | 40 | 50
Cost | 1225,8 | 1639 | 1612,2
Cost per kWp | 1532,25 | 1639 | 1343,5

# Feed-free systems

“It is in response to the overwhelming clamor from our customers for a product that can control the amount of power that the grid tie inverters (GTI) can generate so that the amount of excess power produced by the solar panels are reduced to insignificant levels, if not eliminated ---because in some countries, the producer pays for the excess power it gives to the distribution grid. This is because the electric power meters (the one provided by the electricity provider in the area) are not aware of the direction of power flow. In other words it only adds even if power is exported to the grid, thus, the consumers will be charged for power even if it is given to the grid, and this is the problem” (inverter GTN 1000 info (https://www.aliexpress.com/item/1005003640516861.html) ).

note: ‘Feed-free’ inverters only produce for self-consumption. Excess energy is lost, but it is not fed into the grid: it is simply not produced.

# DIY project C: 800W module

This design is for 800W, ‘feed-free’ modules, with batteries reachable at a later date (see below, D-storage project) and expandable up to 8kW using more modules.
It is a flexible and gradual modular approach, both in terms of performance and cost.


We have two contiguous elements: house switchboard (existing, modified) and PV disconnector, while the inverters can be located in a remote location, as close as possible to the solar panels.

1 – house switchboard
In the main switchboard, I replaced the existing main switch with the following device:

2P 63A TUYA APP WiFi Smart Energy Meter OPWT-63 (https://www.aliexpress.com/item/1005002361164427.html, € 33)

In addition to the measurement functions (V, I, W, kWh) visible on the display, this switch has adjustable protections for:
- Leakage (10-100 mA) (life saver)
- Overcurrent (1-63A)
- Overvoltage (250-300V) delay 0.5s
- Undervoltage (150-190 V) delay 0.5 s

It is Tuya compatible, so with the SmartLife APP you can both configure and read the data. In particular, this Meter provides the energy exchanged with the grid (on the bill) in real time.

In the diagram, the dotted box represents the OPWT-63 Energy Meter

Furthermore, the pre-existing direct connection between the main switch and the disconnectors (in red in the diagram) must be eliminated, in order to pass through the PV control unit

2 – sezionatore PV
The CA control unit consists of two devices - 5 modules - which can be inserted into the house switchboard if there is space available, or they can find their place in a new control unit placed near the existing switchboard.

This manual switch allows you to completely disconnect the AC 230V solar system. ( 50A => 10kW)
2 modules
EARU DZ47 2P (https://www.aliexpress.com/item/4000917622193.html) 400Vwith 50A protection | € 6,03

This DIN PowerMeter is an accessory included with the chosen inverter (https://www.aliexpress.com/item/1005001565429387.html) and measures the power absorbed by the loads using a current probe.
It can control up to 10 inverters via an RS485 link.
Must be set to the number of inverters present.
3 modules.

External watertight control unit for 5 DIN modules
CHYT 5way (https://www.aliexpress.com/item/1005004300793604.html) Plastic Waterproof Distribution Box | € 11,95

2 – connection cables
From the control unit (see diagram) two connections reach the inverters, located near the solar panels:
- 220V bus, (3 poles), 5..50 A to connect the inverters
- RS485 connection, dashed in the diagram: a shielded twisted pair can be used up to a maximum of 100 m.

The characteristics of the cables vary according to the distance and the powers involved: 3-pole double sheath outdoor cable

Diameter to be calculated (https://www.oppo.it/calcoli/cavi/calcolo_sezione_cavo.php) case by case as a function of distance and current. Use, in the link form:
✔ 230 V in EU as alternating voltage
✔ 1.25 as a coeff for the powers (ie 1250 W – 12500 W)
✔ loss < 1% (ie 2 V)

Values for short distances (< 5 m, indicative prices): 4 mm²
: 25A | 5 €/m
6 mm²
: 32 A | 6.50 €/m
Cable for RS485
For short distances (< 10 m): twisted pair
For long distances (< 100 m)
shielded twisted pair (indicative price) | 0.50 €/m

3 – DC control unit + inverter
A single box contains both the DC control unit and the inverter.


Construction site control box, (https://www.leroymerlin.it/prodotti/elettricita-automazioni-e-smart-home/quadri-e-centralini-elettrici/centralini-elettrici/centralino-a-incasso-8-moduli-ip65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) 8 modules. 30,35 € + shipping Requires a front closure panel.

Note: openings can be made or a fan added to improve cooling: in these cases use only indoors.

DC protections: between the panels and the inverter (see diagram)

CHYT DC Surge protection 20-40 KA 600V (https://it.aliexpress.com/item/4001043607240.html) | 12 €
2 modules

Per scollegare i pannelli solari:

EARU Breaker DC EACBDC (1000V) (https://it.aliexpress.com/item/1005004692687373.html)
2P protection 40A | 9,78 €
2 modules

AC protections: between each inverter and the 220V bus (see diagram)

OP2P 63A TUYA APP WiFi Smart Energy Meter (https://it.aliexpress.com/item/1005002361164427.html) WT-63 € 33

This meter allows to connect/disconnect of the single inverter and offers all the necessary protections.
It also provides useful measurements to evaluate the performance of each inverter via WiFi (Tuya compatible).
2 modules

mass distributor
Bare clamp 7 holes (https://it.aliexpress.com/item/32845005334.html) | 2,37 €

4- Inverter feed-free
There are many models of inverters with limiter available. Unfortunately, none are WiFi compatible with Tuya (for this reason I use the OP2P-63A Smart Energy Meter in each module).

In this project, I chose the GTN-1000LIM24 (https://it.aliexpress.com/item/1005003635188042.html) (192,65 €) inverter. It's not a recent model, but it has an excellent cost/performance ratio and some interesting features.

Note: of the same inverter there is also a version without display but with WiFI, the GTN-1000LIM24-W (https://it.aliexpress.com/item/1005003635188042.html) (234 €) model, which uses its own cloud and application (not compatible with Tuya - not tested).
Features:

Input power range: 200W-1100W
PV input range: 26 V – 45 V (pannels 5P2S) Max Input protection current: 40 A
Battery mode (24 V) power range: 90W-650W Battery + limit mode max output: 700 W
Efficiency: 88%

The LIMIT function uses an external sensor and controls, in an open loop, the AC output power, avoiding any extra energy input into the grid.

This inverter has four modes of operation:
1) PV: standard Inverter function, with MPPT for solar panels
2) PV + LIMIT: Operation with solar panel and with current limitation: it supplies only the power required by the loads.
3) BATT: Inverter function from the backup battery (from any DC source).
4) BATT + LIMIT: with battery and current limitation (max. 700 W).

In this project we are interested in mode 2: PV + LIMIT, and using this inverter the project is later expandable with storage batteries (using mode 4).

This inverter can be controlled via RS485, (https://secondlifestorage.com/index.php?threads/limiter-inverter-with-rs485-load-setting.7631/) so it is possible to design a custom integration of the inverter in tuyaDAEMON and to use advanced management strategies (see also an example (https://github.com/KlausLi/Esp-Soyosource-Controller) of remote control).

5- Modularity
The positive aspects of a modular approach are:
- Ability to achieve optimal sizing and adjust to changes.
- Reduction of the consequences of damage or failure, both in functional and cost terms.
- Possibility of modulating investments over time.
- Small-scale tests and checks before major investments.

These modules are expandable simply by using inverters in parallel and setting the inverter number in the probe. The inverters (A, B, C) must be connected 'before' the probe (D), and the domestic loads 'after' the probe: therefore you cannot use just any socket (characteristic of 'plug-and-play') but you must obtain a dedicated connection from the house switchboard (see diagram).


(from GTN-1000LIM24 documentation)

Each inverter can manage solar panels from 200 to 1100 Wp, so even the single module is scalable. Therefore, a continuous upgrade strategy from the plug-and-play module to a 200 Wp C-module is possible, and then increase the power up to 1 kWp by adding pairs of panels.

It is recommended that the solar panels managed by an MPPT inverter all have the same exposure and no shade. More 800 Wp modules can therefore be used both to obtain greater powers and to manage groups of panels with different exposures. (note: some inverters contain multiple independent MPPTs for this purpose).

note: The choice of 800 Wp per module is due to the following criteria (it can be increased to 1 kWh):
- 700W limit in battery operation.
- Using 8 panels as 4P2S with inverter and then as 2P4S with battery controller.
- Positioning of panels in 4x2 or 8x1 rows
- Avoid excessive heating of the inverter.

Project C cost summary – inverter with limit (800 Wp)

(*) optional or variable

una tantum
house switchboard (modified)* | 33
PV AC box | 18
Cables 220 V +RS485 (5m)* | 30
cost | € 81,00
each module (800 Wp)
PV DC box | 85
inverter | 234
8 x solar panels | 693
cost | € 1.012,00
cost per 1 kWp | € 1.185,25
flat roof installation
Support* | 200
mounting accessories, cables* | 97
cost | € 297,00

# Energy storage

Analysis: choice of batteries
There are various battery technologies for PV storage, the most common are:
- Lead-acid batteries: cheap (various types: AGM, GEL, tubular…)
note: automotive batteries are NOT suitable for PV applications.
- Lithium batteries: In rapid development, also due to the demands in the locomotion sector. (various types: Lithium, LiFePO4…). There is also the possibility of self-construction.
- Supercapacitors; New technology, high-end.

Example (Faam, from https://www.iorisparmioenergia.com):

The most important parameters for a technical-economic assessment of storage are:
- Depth of charge (DOD): useful capacity compared to nominal.
- Number of cycles: that is the expected life of the battery. In solar applications a cycle equals one day.
For lead acid batteries, the number of cycles is related to the DOD. Example (Prime AGM battery):
100% DOD | => 300 Cycles | (less than one year)
80% DOD | => 400 Cycles | (1.09 years)
50% DOD | => 700 Cycles | (2 years)
30% DOD | => 1700 Cycles | (4.65 years)
20% DOD | => 2400 Cycles | (6.6 years)
- Costs: analyze the initial cost, the cost per kWh, the maintenance cost, the cost in 20 years (life of the system).

Always check the manufacturer's specifications before choosing a battery.
Note: beware of scams, especially mail order scams, they are very common with lithium batteries. Always check user comments, especially if you find offers at too low prices.

When using batteries (acid or lithium) in series to increase the voltage (for example 12+12 = 24V) it is advisable to use a device that guarantees the balance of the charge: (https://www.huaxiaotech.com/product/2-12V-Battery-Equalizer-Balancer-for-LifePo4-Lithium-battery-pack-Balancer-extend-battery-Life-83.html)
Charge Battery Balancer (https://it.aliexpress.com/item/1005004407261803.html) | 16,99 €

Analysis: storage size
We try to establish rational criteria for evaluating the required storage.
We evaluate the solar energy (Esolar) expected for our system. Let's consider 2 kWp (slope 50°, azimuth 45°): from PVGIS we get (we use a factor of 0.8 for storage losses
2900 kWh – average annual production | => | 6.4 kWh/day (annual average)
146 kWh – production month December => | 3.8 kWh/day (December)
342 kWh – production month July | => | 8,8 kWh/day (July)

Let's consider consumption by dividing it into three categories:
- Constant: we have a fixed ceiling due to equipment that is always on or on standby: burglar alarm, WiFi, TV, etc...
- Scheduleable: these are the consumptions that can be moved to the daytime slot (self-consumption), or by changing habits or, better still, through automation. Examples: Water heater, washing machine, dishwasher, irrigation, etc.
- Random: these are consumptions that can take place at any time of the day or night and cannot, by their nature, be scheduled. Examples: lights, oven and kitchen appliances, refrigerator, air conditioning/heating, fans, TV, PCs, etc.

The energy required for storage (Efrom-storage) is, considering an average of 5 hours of sunshine:

Efrom-storage = 19/24 Econstant + 19/24 Erandom

The energy available for storage (Eto-storage) is, always considering 5 hours of sunshine and indicating with Esolar the energy produced in a day:

Eto-storage = Esolar - Eschedulable – 5/24 Econstant – 5/24 Erandom

A) This consumption can be evaluated a priori, using the plate data of the appliances and considering usage habits. To simplify the calculations, you can use online tools, such as the Trojan Battery Renewable Energy Sizing Calculator. (http://usbattery.com/calculator/energy-chart.html)
B) Or consumption can be evaluated experimentally, measuring actual consumption broken down by type for a period (e.g. one month, better if repeated: summer/winter).


For this purpose, I bought many smart sockets (https://www.aliexpress.com/item/1005003640472196.html) (8.82 €) for the main appliances. These sockets allow you to:

- know the instantaneous and historical consumption of household appliances
- evaluate the current ON/OFF status of the appliance
- suspend/resume operation of the appliance.
- later they will be used for automatic management.

Equivalent, but with a different form factor (https://www.aliexpress.com/item/1005004096965859.html) (14.73 €),

this meter is suitable for fixed installation within existing outlets.

In all cases, TuyaDAEMON saves the data in a DB and therefore can be easily processed to obtain the desired synthesis.

# DIY project D: adding storage

Battery choice
The following general criteria are found in the literature:
- (a) useful battery capacity = from 0.1 to 0.15% of annual consumption
- (b) useful battery capacity = 1.5 × PV array power
- the reference value is the smaller value between (a) and (b).

A quick alternative criterion for evaluating storage needs takes into consideration not consumption, but the energy produced and the self-consumption.

Starting data: PV 1kWp, slope 50°, production 1450 kWh/year. So the average daily production is 3.9 kWh (December 2.4 kWh, July 5.5 kWh).
This table shows the extra energy (excluding self-consumption) available for storage:

A reasonable value for self-consumption is between 50 and 70 percent, so there is energy available for 1..2 kWh of storage (average). Of course, the more storage the better, but it's still a major investment..

I choose to start with 1kWh of storage for each module (1000 Wp). If I can't reach 70% self-consumption I will increase the storage later: it is, therefore, important to use storage that allows the increase by adding batteries in parallel.

To have 1 kWh of useful storage, the battery capacity varies according to the technology (24 V is imposed by the chosen inverter):
Lead batteries | (DOD 50%): 24V – 83 Ah
Lithium batteries | (DOD 80%): 24V – 52 Ah
Supercapacitors | (DOD 99%): 24V – 40 Ah

Examples (some prices are net because the VAT on batteries, in Italy, can be 22% or 10%):

2 x AGM Deep Cycle,12 V 100Ah (https://ryanenergia.it/prodotto/banco-batteria-100ah-24v-ciclica-e-agm-x-uso-fotovoltaico-deep-cycle-long-life/) (SLC 100-12S) 295 € + VAT + transport
output current: max: 60A
10 ÷12 Years of expected lifetime (?)
weight: 2x28 Kg
Self-consumption | storage [kWh]
avg | December | July
0,00% | 3,9 | 2,4 | 5,5
10,00% | 3,51 | 2,16 | 4,95
20,00% | 3,12 | 1,92 | 4,4
30,00% | 2,73 | 1,68 | 3,85
40,00% | 2,34 | 1,44 | 3,3
50,00% | 1,95 | 1,2 | 2,75
60,00% | 1,56 | 0,96 | 2,2
70,00% | 1,17 | 0,72 | 1,65
80,00% | 0,78 | 0,48 | 1,1
90,00% | 0,39 | 0,24 | 0,55
100,00% | 0 | 0 | 0

2x AGM Deep Cycle,12 V 100Ah (https://www.ilportaledelsole.it/batterie-al-piombo-agm-gel/94-batteria-100ah-12v-prime-deep-cycle.html) Prime 324 € + VAT + transport
cycles: 700 (50% DOD)
weight: 2x33 Kg
LiFePO4 24V 60 Ah (https://www.aliexpress.com/item/1005002551132348.html) | 519,63 €
discharge current 40A (960 W)
max 4 series/parallel (BMS limit)
cycles > 3000
weight: 14 Kg
Power adapter included
LiFePO4 24V 54 Ah (https://www.ilportaledelsole.it/batterie-al-litio-ioni-di-litio-lifepo4/5013-batteria-lifepo4-54ah-24v-ultimatron.html) | 690 € + VAT +transport
Recommended/max charge current: 10,8A / 27A
cycles > 3000 (DOD = 80%)
max 2 series/parallel (BMS limit)
Bluetooth 4.0 monitoring via Android and IOS app. weight: 14 Kg

2 x supercapacitors Sirius (https://www.istshop.it/home/246-accumulo-a-supercondensatori-sirius-500wh-12v.html) storage 500Wh 12V 1100 € + VAT + transport
Compatible with AGM charge
max charge/discharge: 40A / 40A
DOD = 99%
life > 40 anni.
weight: 2x11 Kg

The choice is exclusively based on subjective and economic considerations. Surely supercapacitors are the most convenient in the long run, but they are also a new solution with the highest initial cost.

The charging process of a battery is generally divided into 3 phases: rapid, constant voltage, and maintenance. Equalizing charge (https://www.challengebatteries.com.au/wp-content/uploads/2021/08/US-Charging-and-Equilizing.pdf) (for lead acid batteries only) once a month.


(from MC2440N10 documentation)

The values that identify each step depend on the battery voltage and technology and are generally modifiable by the user (always check the datasheets of the battery and the controller used):


(from Demura controller) (https://it.aliexpress.com/item/1005004462493729.html)
For the various types of lead-acid batteries see also here. (https://www.crypton.co.za/Tto%20know/Basics/Batteries/Instruction%20on%20Recharging%20Batteries.pdf)

DIY project D: storage
The elements shown in the figure must be added to project C: the battery pack (with switch and fuse) and the DC/DC charge controller. The pre-existing inverter is no longer connected to the panels but is connected to the battery.


The scheme is substantially identical to that proposed by the manufacturer, apart from switches and protections (often imposed by the standards in force).
It may be advisable to wire the 8 solar panels differently: the controller accepts 26..92 V, and P2S4 reduces cables and currents (and therefore losses).


(from GTN-1000LIM24 documentation)

MPPT solar controller
This model was chosen, among the various controllers available, for its good price/performance ratio and for its well-documented communication interface.
Battery controller SRNE MC2440N10 (https://it.aliexpress.com/item/1005004489509226.html) | 103 €

MPPT: 26… 92 V, max 1320 Wp
battery 24V => 1100W
3-step charge
User manual. (https://github.com/msillano/DIY-photovoltaic-smart/blob/main/documentation/61321868.pdf)
TLL serial port, Modbus protocol. (https://github.com/shakthisachintha/SRNE-Hybrid-Inverter-Monitor/blob/master/src/SRNEinverter.py)


12V-42V DC Circuit Breaker (https://it.aliexpress.com/item/1005004105145415.html) 100A | 8,55 €
6M connections
It acts as a breaker and protection fuse for the batteries.

Cable lugs (https://it.aliexpress.com/item/1005001737844259.html) (10 pcs):

SC10-6 | breaker (7AWG) | 2,62 €
SC10-8 | battery (7AWG) | 2,93 €

Controller/battery/inverter cable recommended in the controller manual (10 mm2 - 7AWG)

AWG7 - 10 mm² (https://it.aliexpress.com/item/1005003408748449.html)
, 2 m (red + black) | 25,67 €

Battery check
There are tools dedicated to checking batteries, for example, BMV 700 Precision Battery Monitor. (https://shop.pkys.com/Victron-Energy-BAM010700000-BMV-700-Precision-Battery-Monitor_p_2810.html) A simpler alternative that can be integrated into tuyaDAEMON (still to be evaluated, depending on the data available from the controller) is the following:
ATORCH tester for batteries, (https://www.aliexpress.com/item/4001246873614.html) 240V, 100A | 20,51 €
with Bluetooth
note: about the ATORCH and his Bluetooth protocol, see this project. (https://github.com/msillano/UD18-protocol-and-node-red)

D project cost summary – storage (1200 Wh )

(*) optional or variabile
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

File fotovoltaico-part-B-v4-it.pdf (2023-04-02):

# DIY Fotovoltaico > 350 Wp

Parte B, Versione 4, 20/03/2023

Come visto nella parte A, (https://github.com/msillano/DIY-photovoltaic-smart/blob/main/fotovoltaico-part-A-v2-it.pdf) anche in caso di autoconsumo al 100%, un sistema plug-and-play da 350 Wp produce un risparmio relativamente basso (11,4 % - 8,4 %) rispetto al consumo annuo di una famiglia di due persone (2000-2700 kWh/anno). Per percentuali maggiori occorre rivedere i progetti.
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

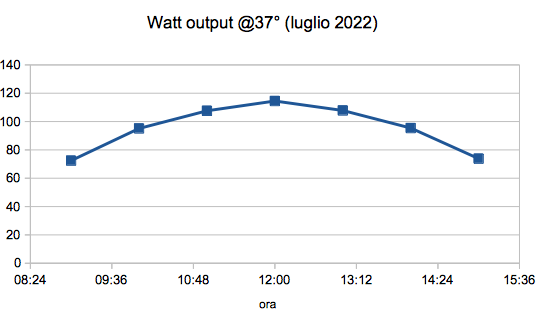
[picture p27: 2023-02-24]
img/Schermata 2022-07-18 alle 13.45.27.png

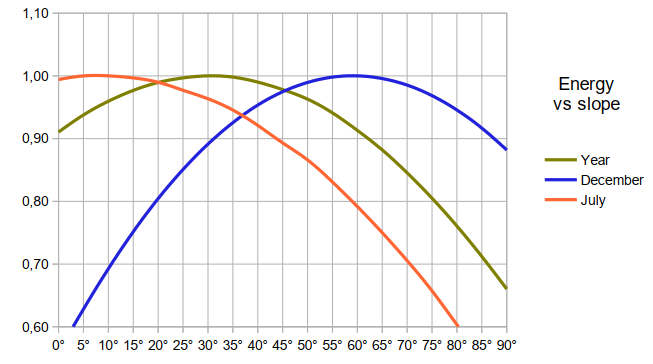
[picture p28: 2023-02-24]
img/energy-slope.png

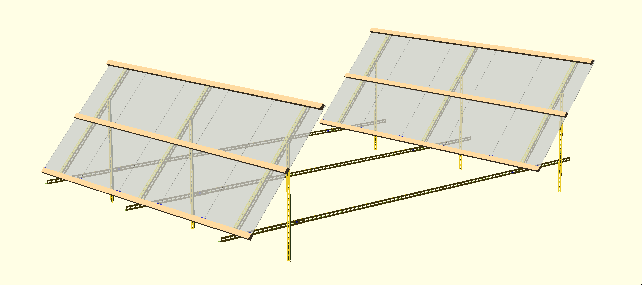
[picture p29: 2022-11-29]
img/panels1000.png

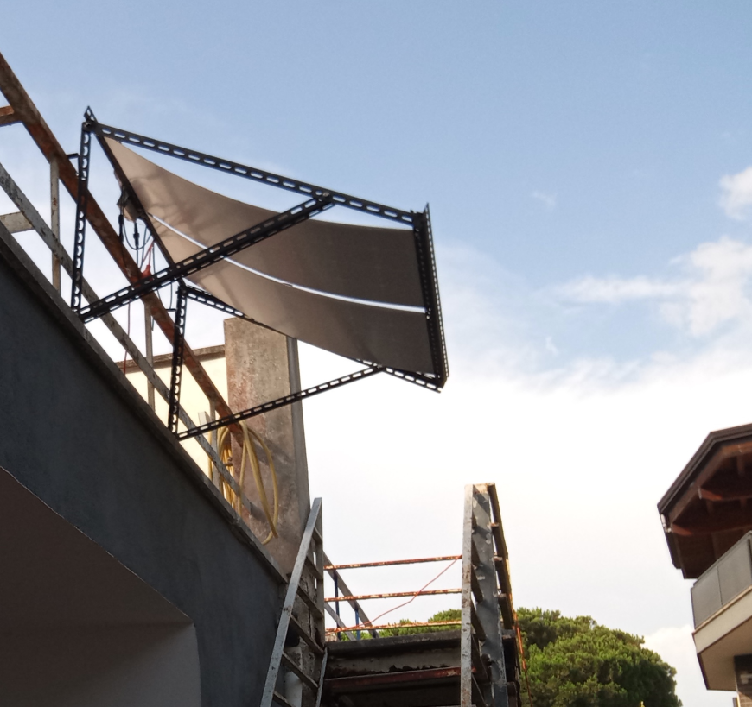
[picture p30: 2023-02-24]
img/pap200.png

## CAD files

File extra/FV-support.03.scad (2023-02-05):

// Paranetric support for PV on floor, wall
// built using L profiles.

// defaults for my project

// PV panel parameters, defaults for RG-MN-100 (external, mm)
PV_vert = 1050;   // size x
PV_hor  =  530;   // size y (rotate: exchange x,y)
PV_s    = 2.5;    // size z
PV_bolt = true;   // false: no holes - for other PV panels
//
PV_string = 5;    // panels on one row (count)
PV_lines  = 2;    // rows of panels, total panels: PV_string * PV_lines (5*2=10)

// support specs
S_slope = 12;      // angle
S_distance = 700;  // between PV rows 
//
S_large = 1600;    // support distance (implicit defines support number)
S_PVclearance = 2; // intra-panel space for fixing, cable, etc... [mm]
S_leg  = 250;      // support leg size: 0 == none ( e.g. on floor)
S_position = 0.6;  // support leg position (0.5: centered)

// parameters for currents (e.g. wood 25x40)
C_number = 3;     // 2..
C_spess = 25;
C_large = 40;

// parameters for L profile (mm)
L_spess = 1;
L_large = 35;
// note hole: dia 10; 10 + 30 = 40 mm, dimensions
L_r = 5;             // radius: set 0 for no holes
L_s = 40;

// design options
spacer_overlap = 100;  // for spacer junction, default 100, 0 for single row
                     // note: you can cut the extra in front of the first panel row 
// anti manifold const
delta=0.1;
clearance = 3;

// ============================================================= derived
S_base    = PV_vert + 2*S_PVclearance;    // panel base
S_hsize   = S_base  * cos(S_slope);       // panel x projection
S_vsize   = S_base  * sin(S_slope);       // panel y projection
S_v       = S_vsize * S_position + L_large + S_leg;                  // vertical element
S_vert    = S_leg == 0? S_v : (L_r > 0)?floor(S_v / L_s)*L_s: S_v;   // round vertical
S_h       = S_hsize *S_position + 2*spacer_overlap + L_large/2;      // horizontal element
S_hor     = (L_r > 0)?ceil(S_h / L_s) *L_s : S_h;                    // round horizontal
S_spacer  = S_hsize *(1-S_position) + S_distance - L_large - 2*clearance; // spacer element
xfootprint= spacer_overlap + PV_lines * S_hsize + (PV_lines -1) * S_distance ; 
yfootprint= PV_string * PV_hor + (PV_string + 1) * S_PVclearance;     
S_nx      = floor((yfootprint-L_large)/S_large);    
S_n       = S_nx > 1 ? S_nx +1:2;                 // support number
S_extrah  =  (yfootprint - L_large - S_large * (S_n -1))/2;   // extra without support
// note: S_large distance between support (support included)
//  ===S=======S=======S===
//  ---+-------+-------++---
//      S_large S_large  S_extrah


// note nut8: 8, 4, 6.4 (mm) => sizes (from standard metric tables).
module nut8(){
    linear_extrude(height = 6.4) circle(r=8, $fn=6);
}

module bolt8(){
   rotate([0,180,0])union(){
       nut8();
       linear_extrude(height = 6.4+6.4+8) circle(r=4);
       translate([ 0, 0, 6.4+2*L_spess]) nut8();
       } 
}

module holeh(n){
    // used by bar()
    translate([ L_r +L_r + n*L_s, L_large/2, - L_spess])
    linear_extrude(height = 3*L_spess){
      hull() {
       translate([L_s - 4*L_r,0,0]) circle(L_r);
       circle(L_r);
        }
    }
}

module holev(n){
    // used by bar()
 translate([0, L_spess, 0]) rotate(a=[90,0,0])
    holeh(n);   
}

module bar(size){
// builds in 0,0,0 a L profile holed bar of size [mm]
difference() {
  cube([size, L_large, L_large]);
  translate([-delta, L_spess, L_spess]){
     cube([size+2*delta, L_large, L_large]);
     }
 if (L_r >0)      
   for (i=[0:size/L_s]){
     holeh(i);
     holev(i); } 
  }
}

// single lateral supports for a panel row
module asupport(){ 
    bar(S_hor);
// vertical element
    translate([S_hsize*S_position+spacer_overlap, delta, S_vsize * S_position +L_large])   rotate(a=[0, 90, -90])bar(S_vert);
//  panel support element
    translate([spacer_overlap, L_spess, L_large + L_spess])   rotate(a=[-90,-S_slope, 0])bar(S_base);
}

// PV_lines ful support with spacers
module fullsupport(){
    if ( PV_lines > 1)for (i =[1:(PV_lines-1)])translate([ (S_hsize + S_distance) *i ,0,0]) asupport();
    if ( PV_lines > 1)for (j =[1:(PV_lines-1)]){
        translate([ S_hsize * S_position + spacer_overlap + L_large + (S_hsize + S_distance)*(j-1) + clearance ,2,2]) bar(S_spacer);
        // only one bolt indicative per junction (use 2 or 3 bolts)
        translate([ S_hsize * S_position + spacer_overlap + L_large + spacer_overlap/2 +(S_hsize + S_distance)*(j-1) + clearance ,2+6,2+L_large/2])color("blue", 0.5)rotate([-90,0,0]) bolt8();
        translate([ S_hsize * S_position + spacer_overlap + L_large + S_spacer - spacer_overlap +(S_hsize + S_distance)*(j-1) + clearance ,2+6,2+L_large/2])color("blue", 0.5)rotate([-90,0,0]) bolt8();
   }
}
// full metal support structure in place
module fieldsupport(){
    for(i=[1:(S_n-1)]) translate([ 0,L_large + S_large*i,0]) {
       asupport(); 
       fullsupport();
       }
  
}    
// single cuttent
module current(){
    rotate([0,-S_slope,0]) color("BurlyWood")cube([C_large,yfootprint ,C_spess]);
}

// adds required currents over the full structure
module addcurrents(){
 for(i =[0:(PV_lines-1)]){
   for( j= [0:C_number-1]){
     translate([spacer_overlap + (S_hsize + S_distance)*i +j*(S_hsize - C_large)/(C_number -1),-S_extrah + L_large/2 ,L_large+j*(S_vsize - 6)/(C_number -1)])current();
    }
  }
}
// single panel in [0,0], default RG-MN-100,  i.e. 6 bolts fixing
module apanel (){
   translate([spacer_overlap + S_PVclearance,-S_extrah + L_large/2+S_PVclearance,L_large + C_spess]) rotate([0, -S_slope,0])
    union(){
     color("DarkGray", 0.5) cube([PV_vert, PV_hor, PV_s]);
// fixing bolts for RG-MN-100, can be changed  
    if (PV_bolt){        
         color("blue", 0.5)translate([20,20,9]) bolt8();
         color("blue", 0.5)translate([20,PV_hor -20,9]) bolt8();
         if ( PV_vert >  PV_hor) {   // it is vertical
           color("blue", 0.5)translate([PV_vert/2,20,9]) bolt8();
           color("blue", 0.5)translate([PV_vert/2,PV_hor -20,9]) bolt8();
         } else {                    // it is horizontal
           color("blue", 0.5)translate([20,PV_hor/2,9]) bolt8();
           color("blue", 0.5)translate([PV_vert-20,PV_hor/2,9]) bolt8();
        }     
         color("blue", 0.5)translate([PV_vert -20,20,9]) bolt8();
         color("blue", 0.5)translate([PV_vert -20,PV_hor -20,9]) bolt8();
        }
    }   
}
// placing a PV panel over currents, in rigth place
module PVpanel (y,x){           // y: line position (0..4), x: line (0..1)
    translate([x*(S_hsize + S_distance), y*(PV_hor + S_PVclearance),0])apanel();
}

// add all PV panels
module addpanels() {
       for(i = [0:PV_lines-1]) 
          for(j = [0:PV_string-1]) 
               PVpanel (j,i);
}

  echo (str("--------------" ));
  echo (str("Panels ",PV_string, "X", PV_lines,", slope: ",S_slope,"°" ));
  echo (str("Footprint: ",xfootprint,  " x ", yfootprint, " mm" ));
echo ();
  echo (str( S_n * PV_lines, " x supports:"));
  echo (str("   base:   ", S_base, " mm"));
  echo (str("   Hbar:   ", S_hor, " mm"));
  echo (str("   Vbar:   ", S_vert, " mm"));
if( PV_lines > 1){
  echo ();
  echo (str( S_n * (PV_lines -1)  ," x spacer: "));
  echo (str("   length: ", S_spacer, " mm"));
}
  echo ();
  echo (str(C_number * PV_lines," x currents:" ));
  echo (str("   length: ", yfootprint, " mm"));
  echo ();
  echo (str(S_n * (PV_lines -1)*4,"/", S_n * (PV_lines -1)*6,  ," x bolts M8x15 "));
  if (PV_bolt) {
      echo (str(PV_string * PV_lines * 6, " x wood screws M 4x30"));} else {
      echo ();
      echo (str("ganasce:"));
      echo (str("   ",(PV_string -1)* PV_lines * C_number, " x omega"));
      echo (str("   ", PV_lines*C_number * 2, " x Z  "));
  }   
 echo ();
 echo (str("Total L: ", ( S_base + S_hor + S_vert)*S_n * PV_lines + S_spacer* S_n * (PV_lines -1), " mm"));
 
echo(str("----------------"));


// project rendering
   asupport();  
// comment to hide some
   fullsupport();
   fieldsupport();
   addcurrents();
   addpanels();
   
